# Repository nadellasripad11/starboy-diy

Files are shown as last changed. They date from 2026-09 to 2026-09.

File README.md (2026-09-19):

# starboy diy

a chrome star keychain with a little animated eye in the middle. shake it and the eye gets dizzy, take it somewhere cold and it starts shivering, yell near it and it gets nervous. leave it alone long enough and it falls asleep.

**see it live → [starboy-diy.nadellasripad11.workers.dev](https://starboy-diy.nadellasripad11.workers.dev/)** (the eyes on the site run the same code as the firmware)

it's my handbuilt take on the [creature starboy](https://lilguy.net). i wanted one, and more than that i wanted to know how one works inside, so i designed the shell from scratch in openscad, picked the smallest parts i could find that would fit, and wrote the eye animations myself.

<p align="center">
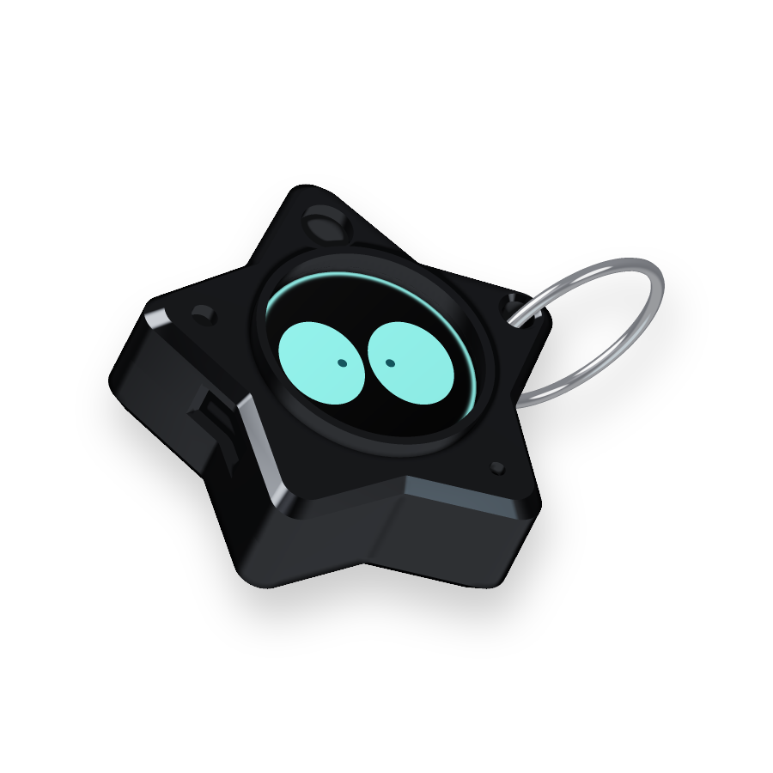
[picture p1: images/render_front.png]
front of the black chrome star shell with the round display and a keyring through its point
  
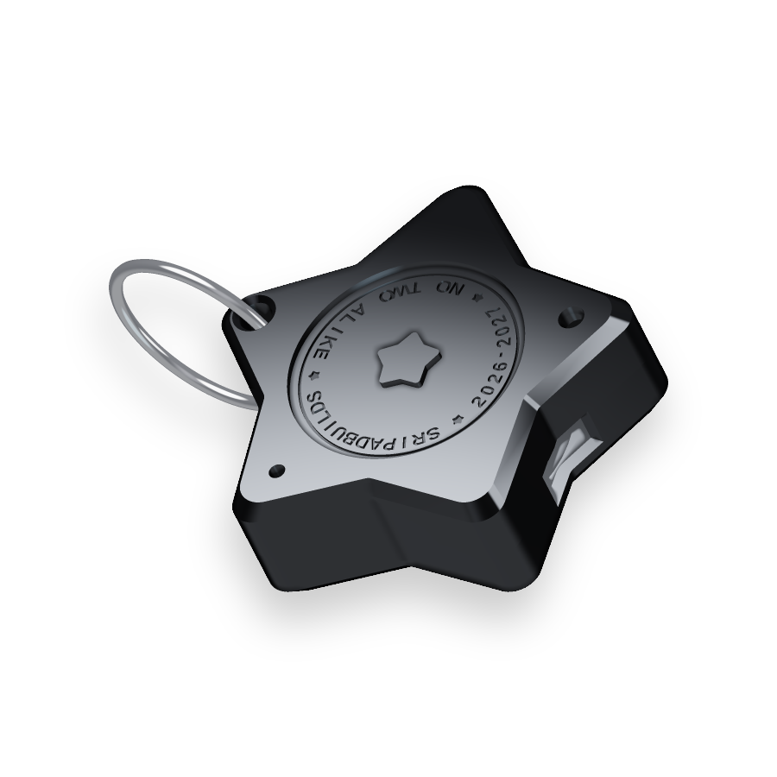
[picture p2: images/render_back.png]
back of the star shell with the engraved sripadbuilds medallion
  
</p>

---

## how it works

the brain is a seeed xiao esp32c3, a board about the size of a thumbnail with a battery charger built in. it drives a 1.28" round screen that acts as the eye, and it listens to three sensors:

- an **mpu6050** that feels shaking and tilting
- a **ds18b20** that pokes out of a tiny vent to read the air temperature
- a **max4466** mic that hears loud sounds

a small lipo sits at the back, and it charges through the xiao's usb-c port, which lines up with a cutout in the shell. the whole thing is 20.5mm thick and clips onto your pants.

---

## what the eye does

| if you... | the eye... |
|---|---|
| shake it hard for a second | gets dizzy, then angry, then calms down |
| take it below 10°c | gets chilly, shivers, then freezes with a blue tint |
| make a loud noise | jumps, then darts around nervously |
| tilt it | looks toward the ground |
| ignore it for 25s | starts dozing and the screen dims |
| ignore it for 75s | falls asleep and breathes slowly |
| shake it or make noise while it sleeps | wakes up |
| just let it sit | cycles through 50 little expressions |
| wait around | every so often plays one of 20 rare effects like rainbow eyes, hearts, glitches, matrix rain or a galaxy swirl |

the first time a star turns on, it rolls one of 100 colorways and one of 4 eye shapes (dot, circle, cat or acorn) and keeps them forever. some colorways are way rarer than others, so your eyes could be a 0.4% pull.

---

## what's in here

- [`cad/starboy_assembly.step`](CAD/starboy_assembly.step): the full 3d assembly (front, back and bezel)
- [`cad/starboy_star.scad`](CAD/starboy_star.scad): the parametric openscad file everything comes from
- [`stl/`](stl/): print-ready front, back and bezel
- [`firmware/`](firmware/starboy_firmware/): the arduino code, the screen config and the pin-by-pin wiring
- [`bom.csv`](BOM.csv): parts, prices and buy links
- [`bom.md`](BOM.md): the same list in plain words, plus how the parts work together
- [`build.md`](BUILD.md): printing, painting and putting it together

there's no custom pcb. everything is hand-wired to the xiao with thin 30awg wire, because that's the only way it all fits in the shell.

---

## what it costs

i'm building two stars, and everything for both comes to **$134.74**, filament included. it's all from amazon, so it shows up in a few days instead of a month. the full list is in [bom.csv](BOM.csv).

most parts come in multi-packs, so only the xiao and the battery get bought twice.

---

## wiring

wiring diagram

every module runs off the xiao's 3.3v pin. if you want every single connection spelled out, it's in [wiring.md](firmware/starboy_firmware/WIRING.md).

---

## printing and finishing

print the three files in [`stl/`](stl/) in white petg. everything gets chromed anyway, so one color is all you need. petg holds up way better than pla when it's hanging off a belt loop every day or sitting in a hot car. orientation and supports are in [build.md](BUILD.md).

for the chrome look, sand it smooth (400, then 800, then 1500), hit it with plastic primer, spray the chrome, and buff it lightly with 0000 steel wool once it's dry.

---

## flashing the firmware

open `firmware/starboy_firmware/starboy_firmware.ino` in the arduino ide, pick **xiao_esp32c3** as the board, and turn on **usb cdc on boot**.

install these from the library manager:

- tft_espi by bodmer
- adafruit mpu6050
- adafruit unified sensor
- dallastemperature
- onewire

one extra step for tft_espi: copy [`user_setup.h`](firmware/starboy_firmware/User_Setup.h) into its library folder so it knows about the round screen and which pins it's on.

before closing the shell, flash [`firmware/hardware_test`](firmware/hardware_test/hardware_test.ino) first. it checks the screen, backlight and all three sensors one by one and tells you which wire to fix. once the real firmware is on, open the serial monitor and type `help` for the tuning console.

both sketches compile clean for the xiao esp32c3 (esp32 core 3.3.11).

### checking everything at once

```
node tools/test_all.js --compile
```

runs the parity check, the mood tests, the seed tests and the demo tour check, then builds both sketches (point `ARDUINO_CLI` at arduino-cli if it isn't on your PATH). drop `--compile` for the 3-second version. the sections below explain each check.

### keeping the eyes in sync

the eye design lives in the firmware and in the website's copy of the renderer. after changing colorways, shapes or thresholds, run:

```
node tools/check_parity.js
```

it checks ~300 values across the firmware, the site, the preview page and the sensor sandbox (colorways, odds, pupil shapes, geometry, thresholds and mood timings), and fails with the exact file and value if anything drifted.

the mood logic has its own tests too, run with a fake clock so the slow paths (freezing, falling asleep) finish instantly:

```
node tools/test_mood.js
```

### choosing a star's eyes

the website rolls eyes with the exact same math as the firmware. tap any look on the [eye looks page](https://starboy-diy.nadellasripad11.workers.dev/eyes.html) and it gives you a command like `seed 1da79c35`. type that in the star's serial console and he gets those eyes for good. it also works backwards: paste the seed a star prints on boot to see which look he rolled.

```
node tools/test_seed.js
```

checks the port against a second reference implementation, confirms the odds over 400,000 rolls, and finds a working seed for all 400 looks.

---

## about the battery

the xiao doesn't have a battery plug, just two little pads on the bottom marked bat+ and bat−. so the plug gets cut off the battery and the wires get soldered straight onto those pads. check which wire is which with a multimeter before soldering, since cheap batteries don't always use red for positive.

a full charge lasts around 4 hours, and the screen dims itself whenever the eye gets sleepy to save power.

---

## credits & legal

this is an **unofficial fan build**. it's inspired by the starboy from [creature](https://lilguy.net), and it isn't affiliated with, endorsed by, or sold by them. "starboy" is their name. i'm not selling these, just building my own and sharing how.

- the shell cad, firmware, website and docs are my own work. **all rights reserved**, so please don't copy, reuse or redistribute any of it without asking first. see [LICENSE](LICENSE)
- the eye style and the 100 colorway colors and odds are based on creature's public eye gallery. the colorway names are my own
- libraries: [TFT_eSPI](https://github.com/Bodmer/TFT_eSPI) (FreeBSD), Adafruit MPU6050 + Unified Sensor (BSD), DallasTemperature + OneWire (LGPL / MIT-style). each keeps its own license
- site fonts are Figtree and Nunito from Google Fonts (SIL Open Font License)

made by [@nadellasripad11](https://github.com/nadellasripad11) · sripadbuilds

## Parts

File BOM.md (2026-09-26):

# bill of materials

everything i need to build **two** stars, bought from the cheapest reliable place for each part. prices checked 2026-09-25.

**total: $91.88** in parts, down from $134.74 when everything came from amazon → [BOM.csv](BOM.csv)

| part | qty | price | where | what it's for |
|---|-----|---|---|---|
| seeed studio xiao esp32c3 | 2 | $9.98 | [seeed studio](https://www.seeedstudio.com/Seeed-XIAO-ESP32C3-p-5431.html) | main board with a built-in lipo charger, one per star |
| gc9a01 1.28" round tft | 2 | $8.96 | [aliexpress](https://www.aliexpress.us/item/3256808098235758.html) | the eye |
| gy-521 mpu6050 | 2 | $3.76 | [aliexpress](https://www.aliexpress.us/item/3256808332288788.html) | shake + tilt |
| max4466 mic amp | 2 | $3.48 | [aliexpress](https://www.aliexpress.us/item/3256805885526362.html) | loud sound detection (pick the max4466 option) |
| ds18b20 to-92 (umw) | 2 | $1.15 | [lcsc C376006](https://www.lcsc.com/product-detail/C376006.html) | cold detection |
| 4.7kΩ resistors (100) | 1 | $0.62 | [lcsc C120071](https://lcsc.com/product-detail/Carbon-Film-Resistors_4-7KR-472-5_C120071.html) | ds18b20 pull-up |
| eemb 402535 3.7v 320mah lipo | 2 | $19.98 | [amazon](https://www.amazon.com/dp/B08215N9R8) | 25.5×36×4.3mm with a protection circuit, one per star |
| 30awg silicone wire, 5 colors | 1 | $6.96 | [aliexpress](https://www.aliexpress.us/item/3256808281675998.html) | wiring inside the shell (pick 30awg) |
| spring carabiner keyrings (10) | 1 | $2.96 | [aliexpress](https://www.aliexpress.us/item/3256807751442375.html) | pants and bag clip |
| stainless split rings 25mm (10) | 1 | $1.53 | [aliexpress](https://www.aliexpress.us/item/3256805611374476.html) | through the keyring hole |
| rust-oleum plastic primer 12oz | 1 | $6.97 | [amazon](https://www.amazon.com/dp/B003CT498U) | lets the chrome stick to the print |
| rust-oleum bright coat chrome 11oz | 1 | $6.47 | [amazon](https://www.amazon.com/dp/B000Z8DGXK) | chrome finish |
| creality petg 1.75mm 1kg | 1 | $14.81 | [aliexpress](https://www.aliexpress.us/item/3256812523172305.html) | star shells and bezel rings |
| prototype board 5×7cm, 1.2mm (10) | 1 | $4.25 | [aliexpress](https://www.aliexpress.us/item/3256807718543888.html) | the board everything solders onto, cut into a circle to sit behind the display |
| | | **$91.88** | | |

## what changed and why

- **aliexpress for the modules.** the display, mpu6050, mic amp, wire and keyrings cost a fraction of the amazon multi-packs. i went by listings with hundreds or thousands of sales and good ratings, not the cheapest one, and priced them at the normal price, not the one-time new-shopper deal.
- **seeed's own store for the xiao.** $4.99 instead of $9.90, and it's the genuine board. the cheap 3-packs on aliexpress don't say they're seeed, and this build depends on the xiao's battery charger.
- **lcsc for the temperature sensor and resistor.** lcsc sells real parts with datasheets. cheap ds18b20s on aliexpress are commonly clones.
- **a prototype board instead of loose wires.** the modules solder onto a small perfboard cut into a circle to sit behind the display (round blank ones aren't sold, so cutting one from a rectangle is the normal way), so everything is mounted instead of hanging on wires. i went with 1.2mm boards, the thinnest common size, because the shell is tight on depth.
- **the battery stays the eemb.** decent aliexpress cells were only about $1 cheaper, with no certification. it's a lithium cell worn on a belt loop, so it's not worth saving $2 on.
- **paint stays on amazon.** spray cans can't be shipped by air from china.

## shipping and fees

the total above is parts only. what gets added at checkout:

- **aliexpress:** shipping and any us import charges are shown in the cart. several of these listings advertise free shipping, and grouping them in one order helps
- **seeed studio:** shipping is shown at checkout
- **lcsc:** shipping plus us tariffs, shown in the cart. it's only two cheap parts, so if lcsc's shipping ends up more than they're worth, an aliexpress ds18b20 pack with good reviews is the fallback
- **amazon:** free shipping on the battery and paint with prime or over $35

## how the parts work together

- everything runs on the xiao's 3.3v rail, and the display, mpu6050, max4466 and ds18b20 are all rated for 3.3v
- the xiao charges the lipo over usb-c, so there's no separate charger board
- the battery's protection circuit handles over-charge, over-discharge and shorts
- the ds18b20 needs one 4.7kΩ pull-up on its data line, soldered on the prototype board
- the prototype board adds 1.2mm to the stack inside the shell, so the shell has to leave room for it
- the to-92 ds18b20 is small enough to sit in the 4mm temperature vent
- 30awg silicone wire folds into the shell without stressing the solder joints

tools not listed (already have them): soldering iron, solder, flush cutters, multimeter, usb-c cable, 3d printer.

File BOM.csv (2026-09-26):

Item Name | Quantity | Unit Price (USD) | Total Price (USD) | Supplier | Link | Notes
Seeed Studio XIAO ESP32C3 | 2 | 4.99 | 9.98 | Seeed Studio | https://www.seeedstudio.com/Seeed-XIAO-ESP32C3-p-5431.html | Genuine board with the built-in LiPo charger; one per star (was $9.90 each on Amazon)
GC9A01 1.28in Round TFT 240x240 SPI | 2 | 4.48 | 8.96 | AliExpress | https://www.aliexpress.us/item/3256808098235758.html | The eye; 4.6 stars and 1000+ sold; one per star
GY-521 MPU6050 Accelerometer/Gyro | 2 | 1.88 | 3.76 | AliExpress | https://www.aliexpress.us/item/3256808332288788.html | Shake and tilt over I2C; 4.7 stars and 500+ sold
MAX4466 Electret Mic Amplifier | 2 | 1.74 | 3.48 | AliExpress | https://www.aliexpress.us/item/3256805885526362.html | Loud sound detection; pick the MAX4466 option (the listing also sells MAX9814); 4.8 stars
DS18B20 TO-92 Temperature Sensor (UMW) | 2 | 0.5751 | 1.15 | LCSC | https://www.lcsc.com/product-detail/C376006.html | LCSC C376006; a real compatible part (cheap AliExpress DS18B20s are often clones)
4.7k Ohm 1/4W Through-Hole Resistor (100 pcs) | 1 | 0.62 | 0.62 | LCSC | https://lcsc.com/product-detail/Carbon-Film-Resistors_4-7KR-472-5_C120071.html | LCSC C120071; DS18B20 pull-up; 100 is LCSC's minimum at $0.0062 each
EEMB 402535 3.7V 320mAh LiPo Battery | 2 | 9.99 | 19.98 | Amazon | https://www.amazon.com/dp/B08215N9R8 | Kept on purpose: UL certified with a protection circuit; AliExpress cells saved about $1 each and are uncertified
30AWG Silicone Wire (5 colors) | 1 | 6.96 | 6.96 | AliExpress | https://www.aliexpress.us/item/3256808281675998.html | Pick the 30AWG option; 4.8 stars and 5000+ sold
Round Spring Carabiner Keyrings (10 pcs) | 1 | 2.96 | 2.96 | AliExpress | https://www.aliexpress.us/item/3256807751442375.html | Pants and bag clip; 4.9 stars and 1000+ sold
Stainless Steel Split Key Rings 25mm (10 pcs) | 1 | 1.53 | 1.53 | AliExpress | https://www.aliexpress.us/item/3256805611374476.html | Goes through the keyring hole in the star's point; 4.8 stars
Rust-Oleum 249323 Automotive Plastic Primer 12oz | 1 | 6.97 | 6.97 | Amazon | https://www.amazon.com/dp/B003CT498U | Aerosol: can't ship from AliExpress or LCSC
Rust-Oleum Bright Coat Metallic Chrome Spray 11oz | 1 | 6.47 | 6.47 | Amazon | https://www.amazon.com/dp/B000Z8DGXK | Aerosol: can't ship from AliExpress or LCSC
Creality PETG Filament 1.75mm 1kg | 1 | 14.81 | 14.81 | AliExpress | https://www.aliexpress.us/item/3256812523172305.html | Official Creality store; shells and bezels for both stars
Prototype Board 5x7cm 1.2mm Single-Sided (10 pcs) | 1 | 4.25 | 4.25 | AliExpress | https://www.aliexpress.us/item/3256807718543888.html | The modules solder onto this instead of hanging on loose wires; cut into a circle about the size of the display (round blank boards aren't sold); 1.2mm is the thinnest common size; 4.9 stars and 10000+ sold
TOTAL (parts only) |  |  | 91.88 |  |  | Before shipping and import fees (see BOM.md); the old all-Amazon list was $134.74

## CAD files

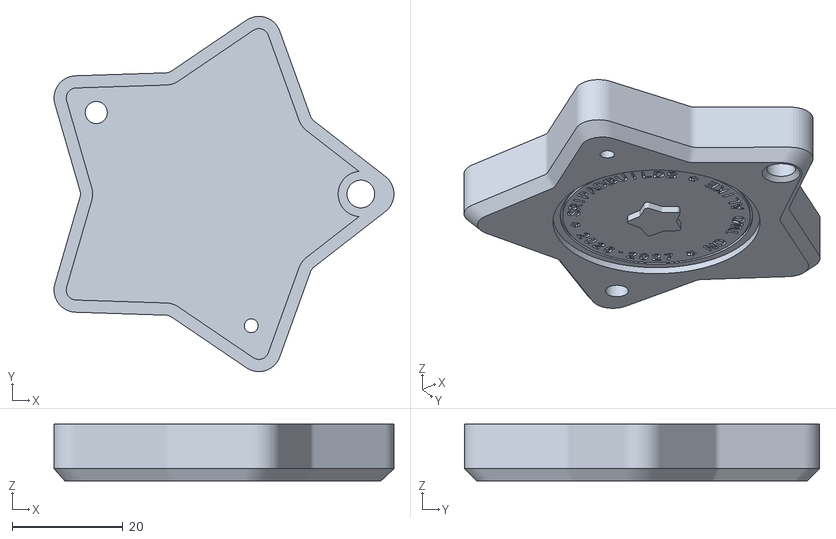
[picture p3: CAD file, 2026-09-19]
stl/starboy_back.stl
61.3 x 64.1 x 10.2

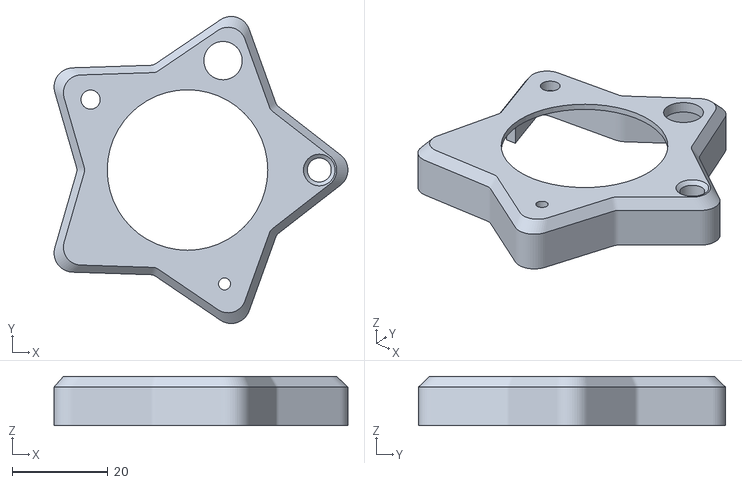
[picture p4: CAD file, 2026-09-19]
stl/starboy_front.stl
61.3 x 64.1 x 10.2

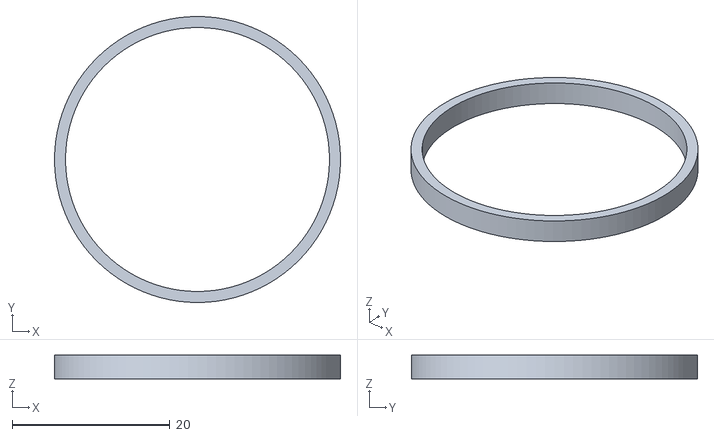
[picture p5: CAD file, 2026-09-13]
stl/starboy_bezel.stl
36.3 x 36.3 x 3.00

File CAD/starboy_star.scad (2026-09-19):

// ============================================================
// STARBOY-STYLE STAR SHELL  (metallic keychain replica, DIY)
// ============================================================
// Free software: OpenSCAD (openscad.org). Open this file, tweak
// the variables below (live preview updates instantly), then set
// `part` (below) to the piece you want and export STL:
//   "front"  -> the front shell half (has the screen pocket)
//   "back"   -> the back shell half (has the engraved medallion)
//   "bezel"  -> just the printable chrome bezel ring around the screen
//   "ring"   -> a printable open jump-ring (or just buy metal ones, see notes)
//   "clip"   -> the pants/pocket clip
//   "preview"-> everything assembled together, for looking at only
//
// PRINT NOTES
// - Print "front" and "back" separately, sand smooth, chrome-spray
//   the OUTSIDE only (mask the inside faces / mating lip if you can).
// - The back medallion is engraved right in the print (text +
//   sunburst + little star badge). You can paint it as-is for a
//   "brushed" look, OR glue a bought engraved steel tag over it if
//   you want real metal there instead — the recess is sized for that.
// - The clip is a plastic spring clip like a pocket-knife clip. PETG
//   flexes better than PLA and is less likely to snap — print the
//   clip in PETG if you have it. Test-fit on your actual pants
//   waistband/pocket edge before gluing it on for good.
// - The "ring" part is a printable open jump ring. Printed rings this
//   small are genuinely more fragile than a $3 bag of metal jump
//   rings — it's included because you asked for it in the file, but
//   for something you'll actually clip to your pants every day, a
//   real metal jump ring/carabiner clip is the safer call.
//
// ============================================================
// COMPONENT FIT — measured, and what drives the dimensions
// ============================================================
// Every number below was used to size the shell. If you swap a part
// for a different one, re-check this table before printing.
//
//   PART                          L x W x H (mm)      WHERE IT GOES
//   GC9A01 1.28" round display    37.5 dia x 5.4      front pocket, centred
//     ^ the PCB. The 32.4 quoted everywhere is the GLASS - sizing to that
//       number is exactly why the pocket had to be re-cut as a step.
//   Seeed XIAO ESP32C3            21.0 x 17.8 x 4.5   behind display, USB-C
//                                                     flush to the 180deg wall
//     ^ has the LiPo charger built in (the SuperMini does NOT). 4.5 is the
//       height over the USB-C socket; the PCB itself is 1.2.
//   MPU6050 GY-521 (no headers)   21 x 16 x ~3.0      stacked behind the XIAO
//     ^ ~3.0 is an estimate (1.6 PCB + chips); not published anywhere.
//   LiPo 402530 (300mAh)          30.0 x 25.0 x 4.0   stacked at the back
//   DS18B20 (TO-92)                4.3 dia x 5.2      at the temp vent, 144deg arm
//   MAX4466 mic board (Adafruit #1063)       x 7.8   at the mic port, 288deg arm
//     ^ 7.8 is Adafruit's figure with the mic fitted. Depth there is ~15 so it
//       fits; footprint wasn't published, so dry-fit it against the arm.
//   OV2640 camera (optional)       8.0 dia lens       camera pocket, 72deg arm
//
// DEPTH BUDGET (the tight axis):
//   body 20.5 - display pocket 5.5 - back wall 3.0      = 12.0 available
//   XIAO 4.5 + GY-521 3.0 + battery 4.0                 = 11.5 used
//   -> 0.5mm slack. Do not reduce body_thickness below 20.5.
//
//   The back wall is 3.0 rather than 2.2 because the medallion dish and
//   its engraving are cut into it. At 2.2 the engraved text punched
//   straight through into the cavity. There is an assert() guarding this.
//
// WIDTH CHECK (the centre region, bounded by the valleys):
//   usable central circle = 2 x (inner_radius - wall) = 41.6 dia
//   battery diagonal sqrt(30^2+25^2) = 39.1  -> fits
//
// The XIAO sits off-centre toward the 180deg valley so its USB-C is flush
// with the inside of the wall; the charge cutout is sized for a cable's
// plastic overmold so the plug fully seats.
// ============================================================

/* [Overall size] */
// Proportions taken off the reference photos: a BIG central mass with
// SHORT, crisp points (the medallion reads ~55% of total width), not
// long thin spikes. The fat centre is also what makes the hardware fit —
// the 32.4mm display needs a ~40mm flat central region to sit in.
star_points      = 5;      // number of lobes
outer_radius     = 36;     // mm, tip-to-centre of each point
inner_radius     = 23;     // mm, valley radius. ~0.64 x outer = reference proportion.
                            // Do NOT drop this: the display's PCB ledge is 19.3mm in
                            // radius and the cavity wall has to clear it. Guarded by
                            // an assert below.
body_thickness   = 20.5;   // mm, total thickness. Sized directly from the measured
                            // component stack — see COMPONENT FIT below. Leaves
                            // 12.0mm behind the display for an 11.5mm stack.
edge_round       = 3.5;    // mm, unused by current geometry, kept for reference
tip_round        = 1.8;    // mm, how rounded each outer tip is in the flat 2D outline
valley_round     = 4;      // mm, how rounded each inner valley is in the flat 2D outline
wall             = 2.2;    // mm, side + front shell wall thickness
back_wall        = 3.0;    // mm, BACK wall is thicker on purpose: the medallion
                            // dish (1.2) plus its engraving (0.5) eat into it, and
                            // at 2.2 the engraved text cut straight through into
                            // the electronics cavity. Leaves a 1.8mm solid floor.

/* [Chamfer] */
// The body is a flat-faced slab (screen/medallion sit flush in true
// flat planes) with a tapered bevel near the top/bottom edges — this
// is what gives the faceted, jewel-cut look in the reference photos,
// instead of an organic rounded blob.
bevel_edge  = 2.2;    // mm, how much of the thickness is tapered at each face
bevel_scale = 0.93;   // profile shrink factor at the very edge of the bevel.
                       // Keep this HIGH (>=0.90). scale() shrinks toward the
                       // origin, so an aggressive value pulls the front face in
                       // past the display pocket edge in the valley directions
                       // and the screen ends up overhanging empty space.

/* [Eye / screen] */
// GC9A01 1.28" round module (Waveshare spec): the 32.4mm figure quoted
// everywhere is the DISPLAY GLASS, not the board — the PCB is Φ37.5mm.
// Sizing a 33.5mm pocket to "32.4mm module" does not fit. So the pocket
// is stepped: a 33.5mm opening at the face that the glass shows through,
// over a wider 38.6mm ledge that actually holds the PCB.
screen_offset_x     = 0;    // centred — margin to the valley edge is tight,
screen_offset_y     = 0;    // don't offset without re-running the asserts
screen_diameter     = 33.5; // mm, the visible opening (glass is 32.4)
screen_pcb_dia      = 38.6; // mm, Φ37.5 PCB + 1.1 clearance
screen_lip_depth    = 1.2;  // mm, depth of the narrow opening = retaining lip
screen_pocket_depth = 5.5;  // mm total; module is ~5.4mm thick
bezel_wall          = 1.4;  // mm, thickness of the printable chrome bezel ring — kept
                              // slim so the display doesn't dominate the face
bezel_height        = 3;    // mm
// The round module is Φ37.5 with a small tab sticking out to 40.4 overall
// that carries the 8-pin header. The notch has to clear that tab: it is
// SHALLOW radially and WIDE tangentially (these two were swapped before,
// which would have fouled the tab).
ribbon_slot_radial = 5;     // mm, how far the notch reaches outward
ribbon_slot_wide   = 14;    // mm, tangential width — tab is ~12mm

/* [Camera — optional] */
// Physical mounting space for a small camera module (e.g. OV2640),
// styled like the lens turret in the reference photos. Not required
// for the shake/cold/sound reactions — only matters if you later add
// face or gesture detection (needs an ESP32-S3 + real image processing,
// well beyond the C3). Cheap to include the hole now either way.
// Sits on the 72-degree arm at r=24: the arm is ~13.2mm wide there, so an
// 8mm lens leaves ~2.6mm of wall each side, and its inner edge clears the
// display bezel (r=18.15) by 1.85mm.
camera_dia          = 8;    // mm, lens opening
camera_bezel_wall   = 1.4;  // mm, raised ring around the lens
camera_pocket_depth = 2.6;  // mm
camera_r            = 24;   // mm from centre, along its arm
camera_ang          = 72;   // degrees
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

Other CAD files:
CAD/starboy_assembly.step

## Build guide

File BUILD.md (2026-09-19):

# STARBOY DIY — Build Guide

Shell: **body ~64 × 61mm, 20.5mm thick**, with the keyring hole through the right-hand point.
Print `stl/starboy_front.stl`, `stl/starboy_back.stl`, and `stl/starboy_bezel.stl`.

Parts, prices and links: **[BOM.csv](BOM.csv)** · **[BOM.md](BOM.md)**

---

## ⚠️ Things that will bite you

**0. The display's "32.4mm" is the GLASS, not the board.** The PCB is
**Φ37.5mm**. Every listing quotes the glass size. The pocket is stepped to
hold the real board — but it also means **Adafruit #6178 will not fit**
(it's a 42.4 × 36.2mm rectangle). Buy a round-PCB module.

**1. The display's pin header.** GC9A01 modules ship with an 8-pin header
soldered to the back. That header sticks ~8mm into the cavity — straight
into the space the XIAO needs. **Desolder it and solder wires flat to the
pads instead.**

**2. The GY-521's headers.** With headers soldered it's ~11mm tall. The
depth budget assumes the board without them (~3.0mm). Leave them off.

**3. Battery thickness is a hard ceiling.** The depth budget is 12.0mm. The
EEMB 402535 in the BOM is 4.3mm thick, which brings the stack to 11.8mm and
leaves just 0.2mm of slack (the CAD was first sized for a 4.0mm cell). Its
36 × 25.5mm footprint fits the cavity rotated 90°. Measure the battery and
the GY-521 before closing up; if they're thicker than listed, the shell's
depth will need adjusting.

**4. Battery wiring.** The XIAO has BAT+ / BAT− **solder pads** on its
underside, not a plug. Cut the battery's JST plug off and solder the wires.
**Check polarity with a multimeter** — cheap leads don't follow one colour
standard, and reversing it can destroy the board.

**5. Charge rate.** The XIAO fast-charges at 380mA — about 1.2× the 320mAh
battery's capacity, above the usual 1C limit. Charge it where you can see
it and unplug it if it gets warm.

---

## Verified fit

Depth is the tight axis. These numbers are asserted at build time in the
SCAD file, so they cannot silently drift:

```
body 20.5  −  display pocket 5.5  −  back wall 3.0    =  12.0mm available
XIAO 4.5   +  GY-521 ~3.0  +  battery 4.0             =  11.5mm used
                                                         0.5mm slack
```

The XIAO's 4.5mm is its height over the USB-C socket. The GY-521's ~3.0mm is
an estimate — nobody publishes it. **Measure both before the final print.**

Width, at the centre (bounded by the valleys):

```
usable central circle          = 41.6mm
battery diagonal (30×25)       = 39.1mm   fits
display PCB                    = 37.5mm   fits (38.6mm ledge)
```

**0.5mm of slack is not much. Dry-fit everything before gluing.**

---

## Feature placement

Front facing you, keyring to the right (0°):

| Angle | Feature | Size |
|---|---|---|
| 0° | Keyring hole, 27.5mm out along the point, sleeved through the hollow | 5mm, through, chamfered |
| 72° | Camera pocket (optional) | 8mm |
| 144° | DS18B20 vent | 4mm, through |
| 180° valley | USB-C charging cutout | 12.5 × 7.0mm |
| 288° | Mic sound port | 2.5mm, through |

The charging cutout is sized for a cable's **plastic grip**, not just the
metal plug — with a tight hole, the grip hits the wall before the plug seats.

The temp vent and mic port are **through-holes on purpose**. The DS18B20
must see outside air — sealed inside it just reads the board's own waste
heat and the cold/shiver behaviour never fires. Seat the sensor body in
the hole; that plugs it.

---

## Printing

- **Front half:** outer face **down** on the bed. No supports: the keyring
  hole is a plain vertical hole with a chamfer at the face.
- **Back half:** flat mating side **down**, engraving facing up. Supports
  (build plate only; tree supports come out easiest) inside the hollow —
  its roof is an unsupported span. Don't print it face-down: the 36mm
  medallion dish would print as a sagging bridge and wreck the text.
- **Bezel ring:** flat, no supports. It glues **on top of** the front face
  around the opening.
- **Layer height:** 0.16mm or finer — the back engraving is only 0.5mm deep.
- **Walls:** 3+ perimeters. The shell is load-bearing round the keyring hole.
- **Material:** PETG. The keyring hole takes the load every day, and PETG
  handles that (and a hot car) far better than PLA. White for everything,
  since it all gets chromed.
- **Do not scale.** Every clearance here is absolute.

### Finishing
Sand 400 → 800 → 1500, Rust-Oleum plastic primer, then Rust-Oleum Bright
Coat chrome on the **outside only**. Keep paint off the flat faces where the two halves meet —
paint thickness there will stop them seating. Polish with 0000 steel wool.

---

## Assembly order

1. Dry-fit the whole stack first. Confirm the halves close before any glue.
2. Leave the headers off the display and GY-521; wire them flat.
3. Drop the display into the front half **from the inside** — the board
   (Φ37.5mm) is wider than the 33.5mm face opening, so it seats against the
   lip from behind. Then glue the bezel ring onto the outside of the face.
4. XIAO behind the display, pushed toward the 180° valley so its USB-C sits
   **flush against the inside of the wall**. Plug a cable in and make sure it
   seats fully before gluing.
5. GY-521 flat behind the XIAO — keep it parallel to the star's face, since
   shake and tilt depend on its orientation.
6. DS18B20 into the 144° vent, mic into the 288° port.
7. Battery last, at the back: solder to the XIAO's BAT+ / BAT− pads,
   polarity checked.
8. Flash and test **before** closing the shell.

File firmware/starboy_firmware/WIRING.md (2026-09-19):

# STARBOY DIY — Wiring, Libraries & Physical Build

## Shell dimensions (final, print-ready)

| | |
|---|---|
| Body | ~64 × 61 mm, keyring hole through the right-hand point |
| Thickness | 20.5 mm |
| Board | Seeed XIAO ESP32C3 (built-in LiPo charger) |
| Display | GC9A01 1.28" round, centred in the front face |
| Charging | XIAO's USB-C, through a cutout in the valley opposite the keyring |

The 20.5mm thickness is not arbitrary — it's driven by the component stack.
See the COMPONENT FIT table at the top of `CAD/starboy_star.scad`.

## Component placement

Looking at the **front** (display facing you), with the keyring at the right
(0°), features sit on the arms at these angles:

| Angle | Feature |
|---|---|
| 0° | Keyring hole (5mm, through) |
| 72° | Camera lens pocket (8mm) — optional |
| 144° | DS18B20 temperature vent (4mm, through-hole) |
| 180° (valley) | USB-C charging cutout (12.5 × 7.0mm) |
| 288° | MAX4466 mic sound port (2.5mm, through-hole) |

**The temperature vent is a through-hole on purpose.** If you seal the
DS18B20 inside, it reads the board's own waste heat and the cold/shiver
behaviour never triggers. It has to see outside air.

## Internal stack (front to back)

```
front face
  ├─ GC9A01 display        5.4mm   (inserted from inside, against the lip)
  ├─ XIAO ESP32C3          4.5mm   (USB-C flush against the 180° wall)
  ├─ GY-521 (no headers)  ~3.0mm
  └─ EEMB 402535 320mAh    4.3mm   (36 × 25.5mm, lies rotated 90° in the cavity)
back face
```
Total 11.8mm into 12.0mm available — only 0.2mm slack. The CAD was first
sized for a 4.0mm 402530 cell; the 402535 in the BOM is 0.3mm thicker. Its
footprint was checked against the real star outline (1.0mm to spare), but
the depth is now very tight and the GY-521's ~3.0mm is an estimate. Measure
the battery and the GY-521 when they arrive and dry-fit before gluing.

## Charging

The XIAO ESP32C3 has a LiPo charger built in (380mA fast / 40mA trickle).
Plug USB-C into the cutout and it charges the battery on its BAT pads. No
extra charger module is needed.

---

# Wiring & Libraries (v2.0 firmware)

## 1. Install TFT_eSPI (requires one-time config)

1. Arduino IDE → Library Manager → search **TFT_eSPI** by **Bodmer** → Install
2. Find your Arduino libraries folder (usually `Documents/Arduino/libraries/TFT_eSPI`)
3. Copy [`User_Setup.h`](User_Setup.h) from this folder into that library folder,
   **replacing** the existing `User_Setup.h`
4. This tells TFT_eSPI: GC9A01 driver, 240×240, and your exact SPI pins

## 2. Install the rest (Library Manager)

| Library | Author |
|---|---|
| Adafruit MPU6050 | Adafruit |
| Adafruit Unified Sensor | Adafruit |
| DallasTemperature | Miles Burton |
| OneWire | Jim Studt |

Board: **ESP32 (by Espressif)** → pick **XIAO_ESP32C3**
Also set: **USB CDC On Boot → Enabled** (so Serial.print debug works)

---

## Wiring

Pins are written as the XIAO's silkscreen label, with the GPIO number the
firmware uses in brackets. D0 (GPIO2) and D9 (GPIO9) are left free on
purpose — they're boot-mode strapping pins.

### GC9A01 1.28" Round TFT (SPI)
| TFT Pin | XIAO ESP32C3 |
|---|---|
| VCC | 3V3 |
| GND | GND |
| SCL/SCK | D8 (GPIO8) |
| SDA/MOSI| D10 (GPIO10) |
| DC | D6 (GPIO21)  |
| CS | D3 (GPIO5) |
| RST | 3V3 (tied high) |
| BL | D2 (GPIO4) — PWM, firmware dims it when asleep; do NOT tie to 3.3V |

### MPU6050 / GY-521 (I2C)
| GY-521  | XIAO ESP32C3 |
|---|---|
| VCC | 3V3 |
| GND | GND |
| SDA | D4 (GPIO6) |
| SCL | D5 (GPIO7) |
| AD0 | GND (address 0x68) |

### DS18B20 (OneWire)
| DS18B20 | XIAO ESP32C3 |
|---|---|
| VDD | 3V3 |
| GND | GND |
| DATA | D7 (GPIO20)  |
| (4.7kΩ resistor between DATA and VDD — comes in the DS18B20 pack) |

### MAX4466 Mic (analog)
| MAX4466 | XIAO ESP32C3 |
|---|---|
| VCC | 3V3 |
| GND | GND |
| OUT | D1 (GPIO3) |

### LiPo battery
| Battery | XIAO ESP32C3 |
|---|---|
| + | BAT+ pad (underside) |
| − | BAT− pad (underside) |

Cut the JST plug off and solder. **Check polarity with a multimeter first.**

---

## What it does — full behavior list

**Sensor-driven states:**

| Trigger | Behavior |
|---|---|
| Shake 1s+ | Dizzy spinning eyes → severe dizzy → recovering → angry |
| Keep shaking hard | Full rage state (deep red squint + heavy furrow) |
| Temp < 10°C | Chill → shiver → freeze (progressively icier, blue tint, crystalline overlay) |
| Loud sound | Startled → anxious darting eyes → overwhelmed |
| Tip it more than 25° from how it's been resting | Eyes look downhill, then settle within a few seconds as he gets used to the new angle (so hanging on a belt loop doesn't keep him tilted or awake) |
| 25s no interaction | Doze — eyes half close, brows droop, backlight dims |
| 75s no interaction | Full sleep — slow breathing blink, occasional dream state, backlight nearly off |
| Shake or sound during sleep | Wakes up ("just woke" expression) |

**Idle personality (cycles automatically, ~2.5-7s):**
neutral · content · happy · curious · bored · wondering · playful · glancing ·
cheerful · relaxed · shifty · noticing-something — 50 base expressions, each
blended smoothly into the next.

**Rare special animations** (checked every ~90s, 40% chance):
rainbow eyes · heart pupils · star pupils · glitch · matrix rain · hypnotic
spiral · loading spinner · error/X eyes · derp/cross-eyed · smug · crying ·
laughing · shocked · "dead" eyes · galaxy swirl · heartbeat pulse · fire
pupils · starfield dream · scanline glitch — 20 total, ~5 seconds each.

**Eye design:** each unit rolls its eyes on first boot (seed stored in
flash): one of 100 colorways and one of 4 shapes (dot 10%, circle 40%,
cat 30%, acorn 20%). Colorways are weighted, so the rarest ones come up
about 0.4% of the time.

---

## Test the parts first

Before soldering everything into the shell, flash
[`firmware/hardware_test/hardware_test.ino`](../hardware_test/hardware_test.ino).
It flashes the screen red/green/blue/white, fades the backlight, then checks
the MPU6050, DS18B20 and mic one by one and prints PASS/FAIL on the screen
and over Serial (115200). After that it goes live: shake it and the SHAKE bar
moves, clap and the SOUND bar moves. Every FAIL line says which wire to check.

## Upload Settings (Arduino IDE)

- Board: XIAO_ESP32C3
- USB CDC On Boot: Enabled
- If an upload won't start: hold the **BOOT** button, tap **RESET**, release BOOT, then upload.

## Tuning

No reflashing needed. Open the Serial Monitor at 115200 with newline line
endings and type commands:

```
status                 sensors, current mood, eyes and every threshold
hw                     which parts are detected, with the wire to check for anything missing
demo                   a ~77s tour for filming: loud room, cold, shaken, four rare effects,
                       falling asleep and waking up. `demo stop` ends it early
debug on               print shake / temp / sound once a second
set shake 12           shake needed to get dizzy (m/s² above gravity, default 16)
set cold 8             °C that starts the shiver (default 10)
set loud 900           mic swing that makes him anxious (default 600, depends on the gain trimmer)
set doze 25            seconds alone before dozing (default 25)
set sleep 75           seconds alone before full sleep (default 75)
set rare 90            seconds between rare effect chances (default 90)
set tempoffset -3      correct the temperature reading (default 0). the sensor sits next to
                       the board and battery, so compare `status` with a real thermometer once
save                   keep the values after a restart
defaults               back to factory values

mood shiver            jump to any mood (help lists them all)
fx fire                play any rare effect
fake temp 2            pretend it's cold, fake sound 2000 pretends it's loud, fake off
reroll                 roll new eyes, seed 1a2b3c4d sets exact ones
```

A good tuning loop: `debug on`, leave the star still for a minute to see
the quiet mic level, then set `loud` a few hundred above it.

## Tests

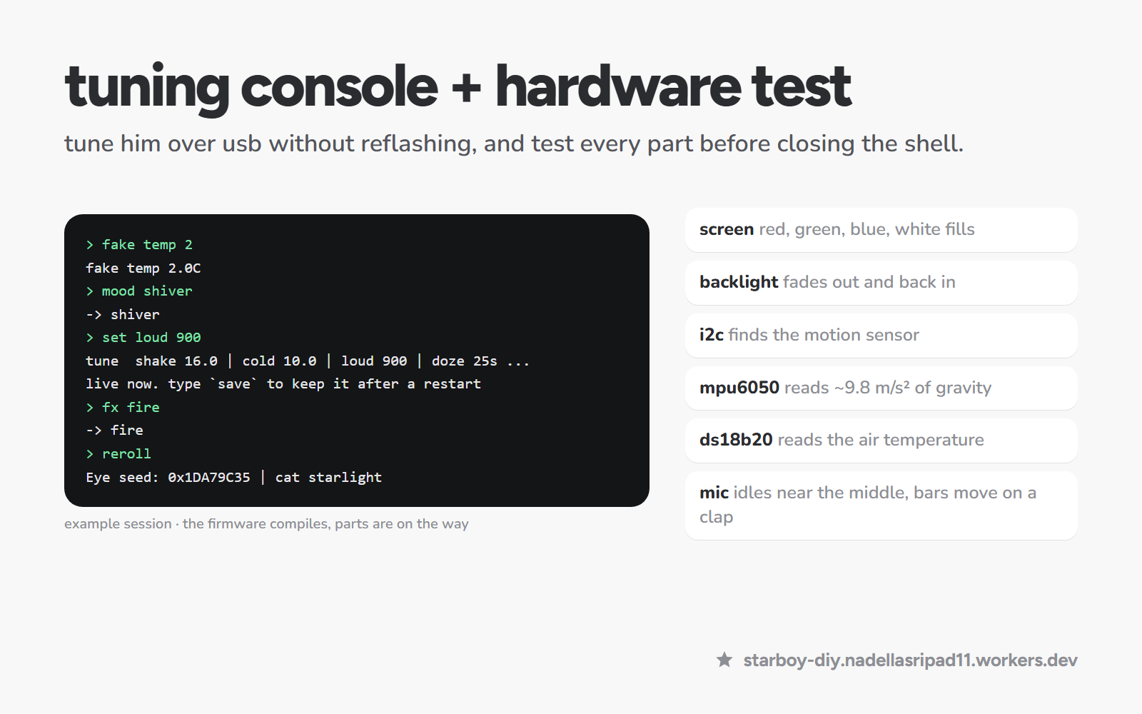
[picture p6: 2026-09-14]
devlog/photos/devlog3/4-console-and-hardware-test.png

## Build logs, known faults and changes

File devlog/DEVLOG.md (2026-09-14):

# devlog #2 · starboy diy

**tl;dr** i'm building a tiny wearable pet from scratch. he clips onto your belt loop, has a round screen for a face, and reacts to shaking, cold and loud noises. the shell, eyes and firmware are done, parts are next.

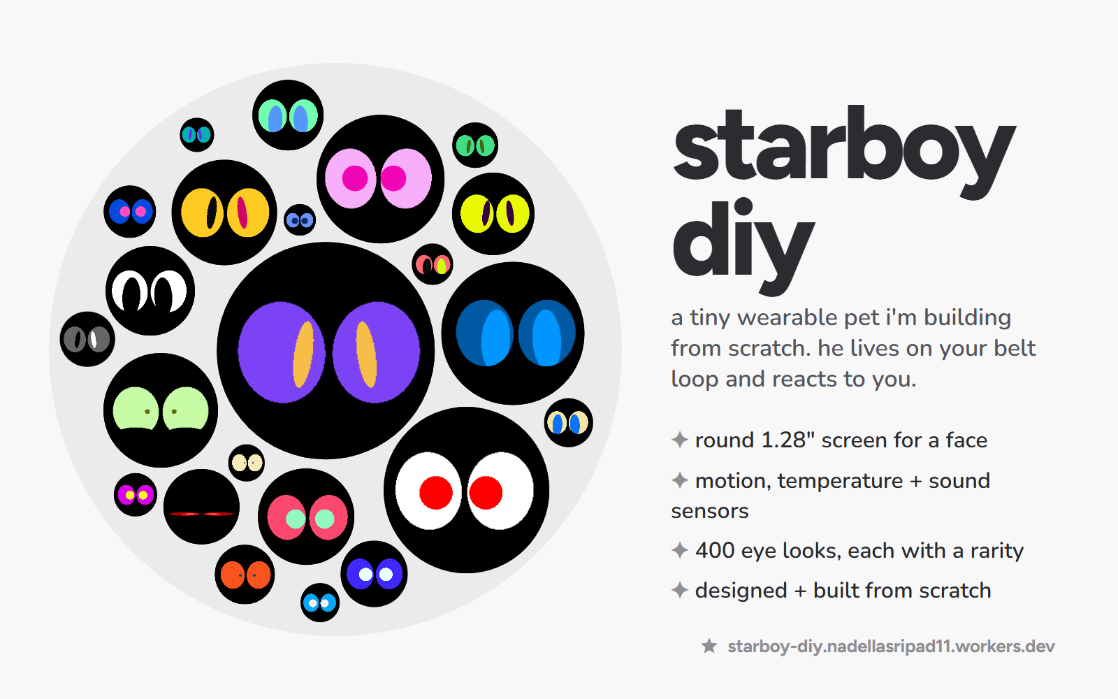
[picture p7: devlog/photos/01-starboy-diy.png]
starboy diy


---

## what i'm making

a chrome star about the size of a keychain, with a 1.28" round screen in the middle that acts as his eye. inside is a thumb-sized esp32 board and three sensors: an accelerometer, a temperature sensor and a microphone. shake him and he gets dizzy then mad. take him somewhere cold and he shivers. yell near him and he gets nervous. ignore him and he falls asleep.

## designing the shell

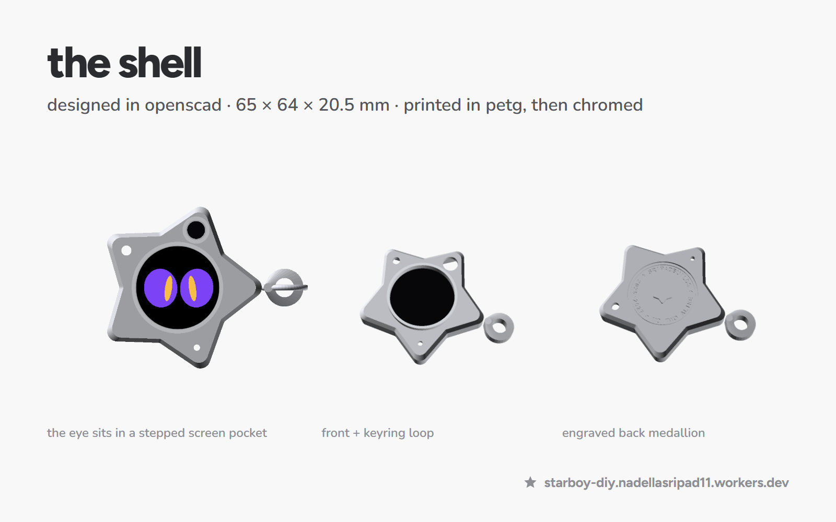
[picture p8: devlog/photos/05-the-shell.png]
the shell


i designed the whole shell in openscad. the hardest part was depth. the screen, board, motion sensor and battery all stack inside a body that's only **20.5mm** thick, which leaves **0.5mm** of slack. i put asserts in the cad file so if a dimension ever changes and something stops fitting, it refuses to build instead of letting me print a broken shell.

one thing that bit me: every listing says the round screen is 32.4mm, but that's just the glass. the actual circuit board is **37.5mm**. so the screen pocket is stepped: a narrow opening you see through, with a wider ledge behind it that holds the board.

the back has an engraved medallion, and there are through-holes for the temperature sensor and mic so they read the outside air instead of the heat from the board.

## the eyes

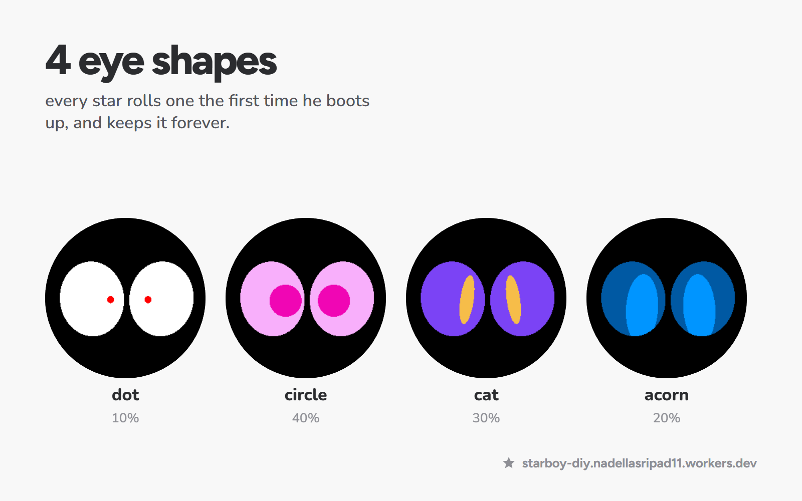
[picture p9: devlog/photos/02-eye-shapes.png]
4 eye shapes


this is the part i'm proudest of. every star rolls his own eyes the first time he turns on and keeps them forever. there are **4 shapes** (dot, circle, cat and acorn) and **100 colorways**, so **400 looks**, each with its own rarity. the rarest ones only come up 0.04% of the time.

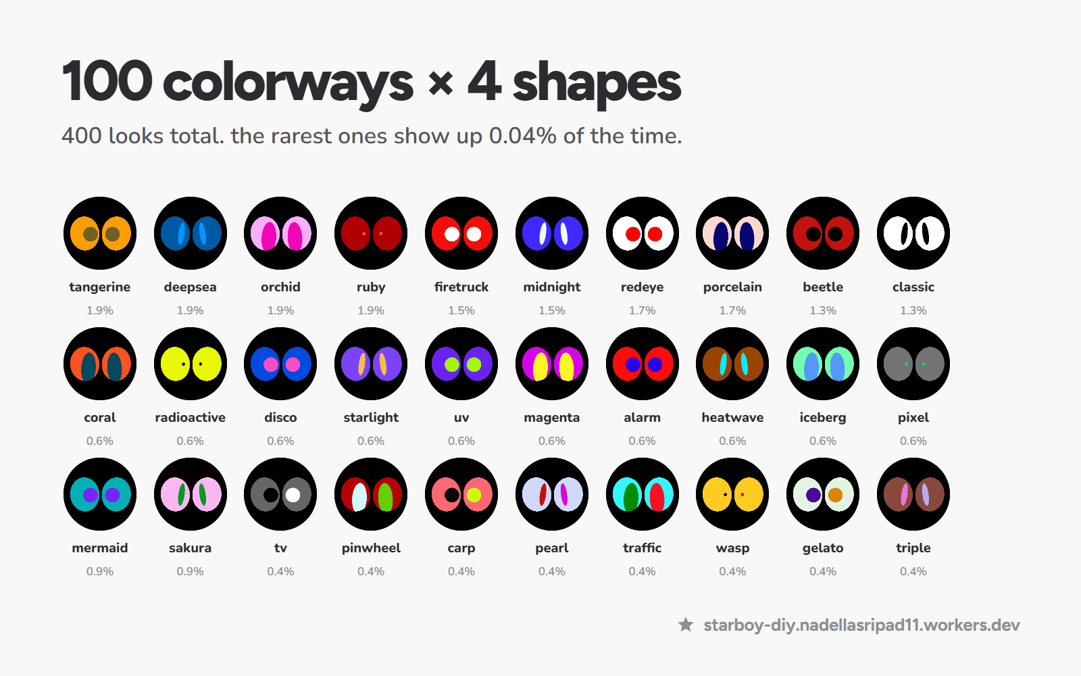
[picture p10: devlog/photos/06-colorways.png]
100 colorways


each eye is drawn row by row on a 240×240 screen: a tilted oval with a pupil clipped to its edge. blinks squash the eye instead of just covering it, and happy moods push the bottom lid up into a little arch.

## making him react

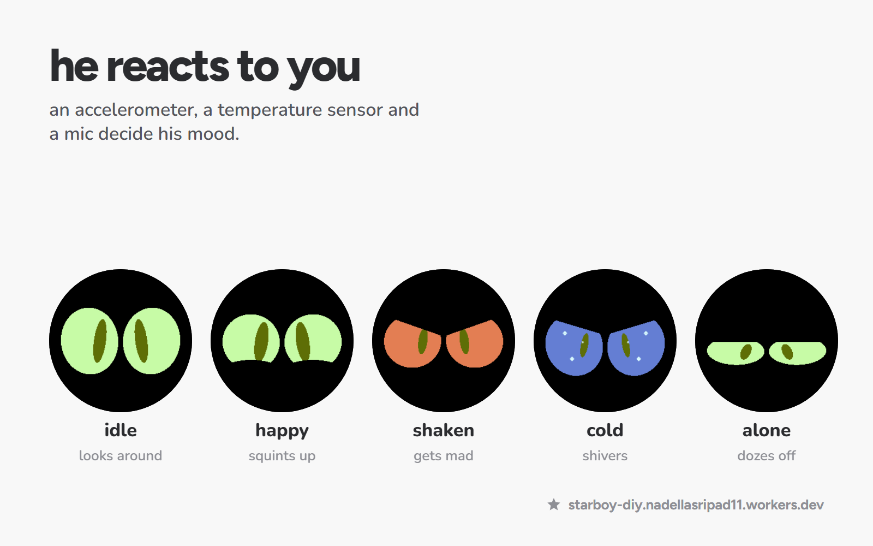
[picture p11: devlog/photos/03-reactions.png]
reactions


the firmware is a state machine. shake him for a second and he spins dizzy, then gets grumpy. below 10°c he turns icy blue and shivers. a loud sound makes him jump and dart his eyes around. after 25 seconds alone he dozes, after 75 he's fully asleep and dreaming, and the backlight dims so the battery lasts longer.

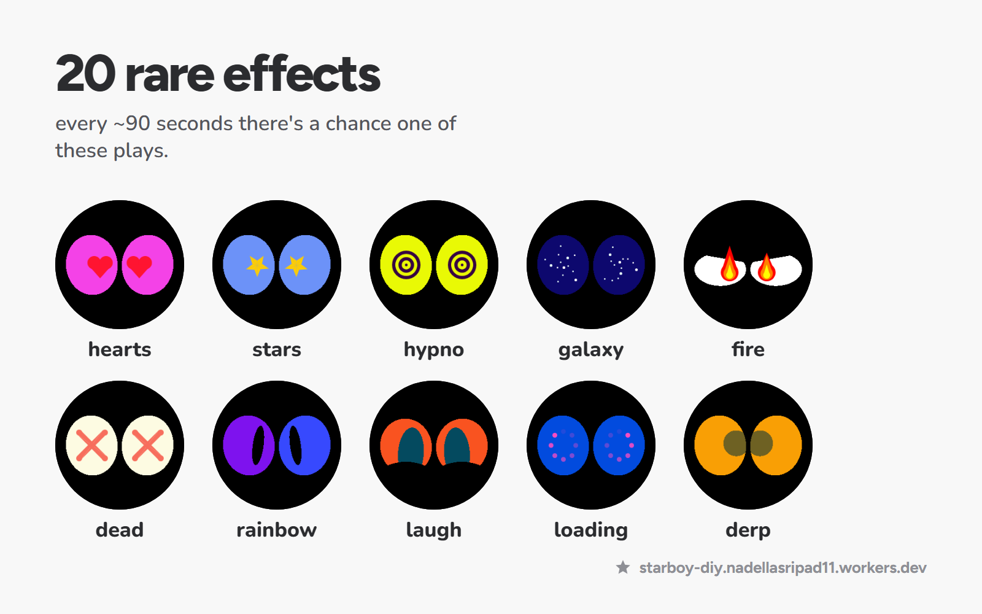
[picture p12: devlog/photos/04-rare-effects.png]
rare effects


and every ~90 seconds there's a chance he plays one of 20 rare effects: heart eyes, spinning stars, hypno rings, a galaxy, fire, X eyes and more.

## wiring

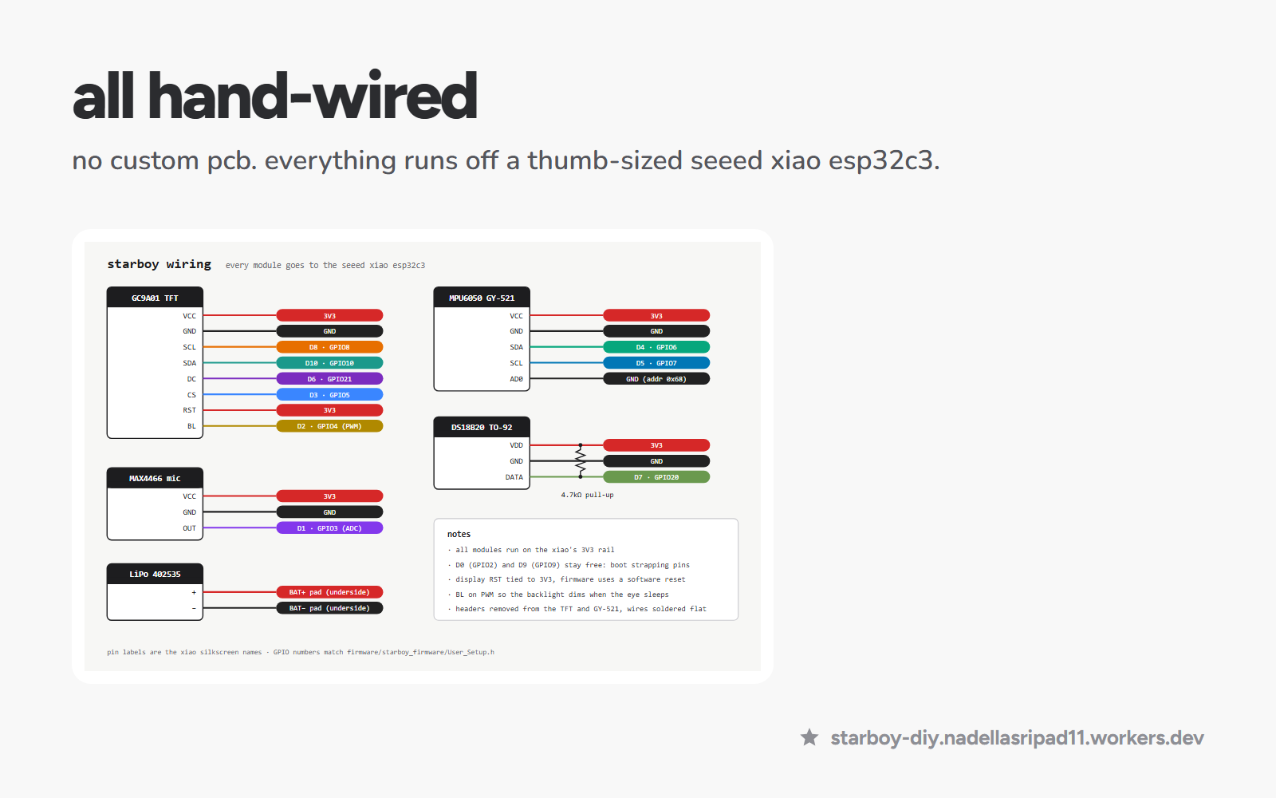
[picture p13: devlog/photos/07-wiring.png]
wiring


there's no custom pcb. everything is hand-wired to a seeed xiao esp32c3 with thin 30awg silicone wire, because that's the only way it all folds into the shell. the xiao also has a battery charger built in, so he charges over usb-c through a cutout in the side.

## parts

i first planned to order everything from aliexpress, but shipping takes 15–40 days, so i moved every part to amazon instead. most parts come in multi-packs, so i'm building two.

## a website you can play with

i built a site where the eyes follow your cursor and you can trigger every reaction and rare effect. it runs the same eye code as the real firmware:
**[starboy-diy.nadellasripad11.workers.dev](https://starboy-diy.nadellasripad11.workers.dev/)**

## what's next

- parts arrive, then i print the shell in petg and paint it chrome
- solder everything and flash the firmware onto the real screen for the first time
- tune the sensor thresholds so he reacts at the right moments
- post the first video of him actually alive 👀

follow along if you want to see him wake up for the first time.

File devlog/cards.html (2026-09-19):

# starboy diy

a tiny wearable pet i'm building from scratch. he lives on your belt loop and reacts to you.

round 1.28" screen for a face

motion, temperature + sound sensors

400 eye looks, each with a rarity

designed + built from scratch

## 4 eye shapes

every star rolls one the first time he boots up, and keeps it forever.

## he reacts to you

an accelerometer, a temperature sensor and a mic decide his mood.

## 20 rare effects

every ~90 seconds there's a chance one of these plays.

## the shell

designed in openscad · 65 × 64 × 20.5 mm · printed in petg, then chromed



the eye sits in a stepped screen pocket



front + keyring



engraved back medallion

## 100 colorways × 4 shapes

400 looks total. the rarest ones show up 0.04% of the time.

## all hand-wired

no custom pcb. everything runs off a thumb-sized seeed xiao esp32c3.



## sensor sandbox

be his sensors on the website. same mood logic as the real firmware.

shivering

temperature2°c

noisequiet

tiltflat

hold to shake

chilly · below 10°c → shivering · below 5°c

## 3 bugs caught before the parts arrived

i wrote tests for his mood logic with a fake clock. they found these.

→

shaking froze his eyes

the dizzy spin never played while you were still shaking him.

fixed: he spins now

→

a belt loop = tilted forever

hanging upright read as 90° tilt, so he'd never sleep and drain the battery.

fixed: he gets used to it

→

asleep and deaf

my battery saver meant he only listened 3% of the time while sleeping.

fixed: a clap wakes him

22mood tests5eye seed tests310firmware ↔ website checks

## pick his eyes

tap any of the 400 looks on the site and get the exact seed that gives a real star those eyes.

cat starlight

0.17% · rare

type this in the star's serial console:

seed 1da79c35copy

## tuning console + hardware test

tune him over usb without reflashing, and test every part before closing the shell.

> fake temp 2 fake temp 2.0C > mood shiver -> shiver > set loud 900 tune shake 16.0 | cold 10.0 | loud 900 | doze 25s ... live now. type `save` to keep it after a restart > fx fire -> fire > reroll Eye seed: 0x1DA79C35 | cat starlight

example session · the firmware compiles, parts are on the way

screen red, green, blue, white fills

backlight fades out and back in

i2c finds the motion sensor

mpu6050 reads ~9.8 m/s² of gravity

ds18b20 reads the air temperature

mic idles near the middle, bars move on a clap

starboy-diy.nadellasripad11.workers.dev

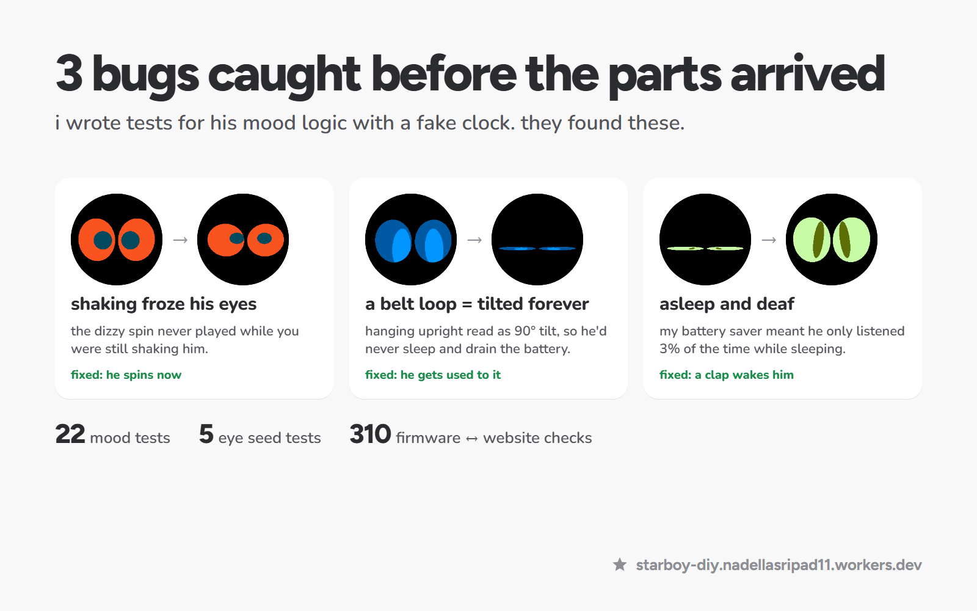
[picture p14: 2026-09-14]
devlog/photos/devlog3/2-bugs-caught.png

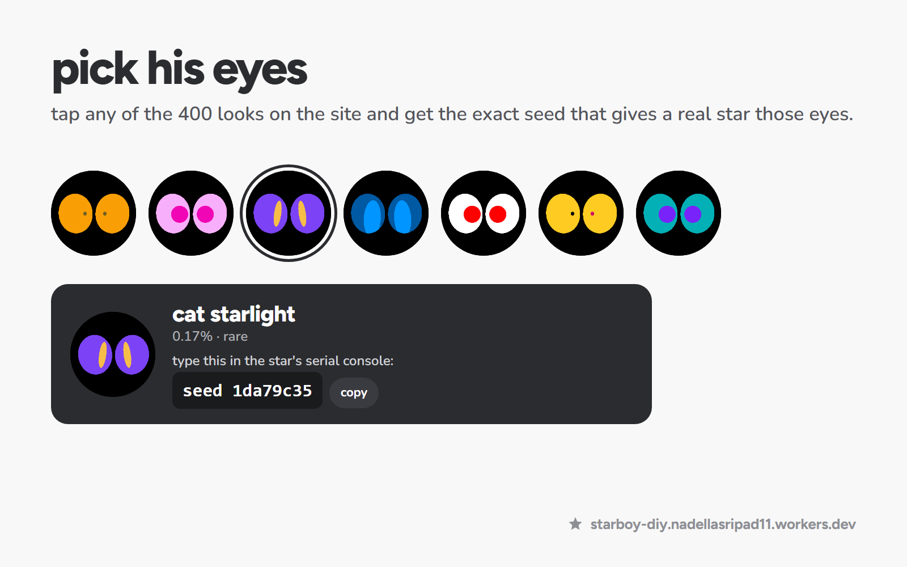
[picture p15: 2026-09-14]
devlog/photos/devlog3/3-pick-his-eyes.png

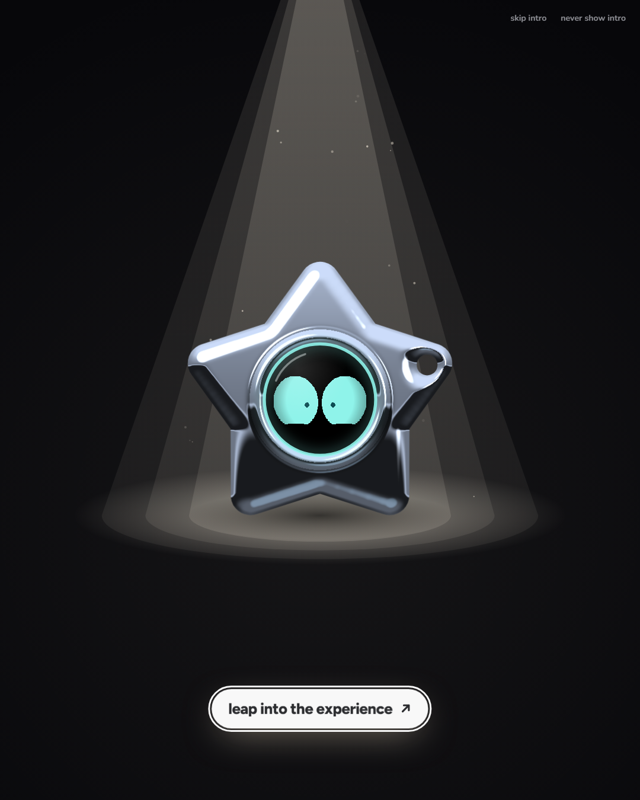
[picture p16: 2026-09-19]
devlog/photos/devlog4_intro.png

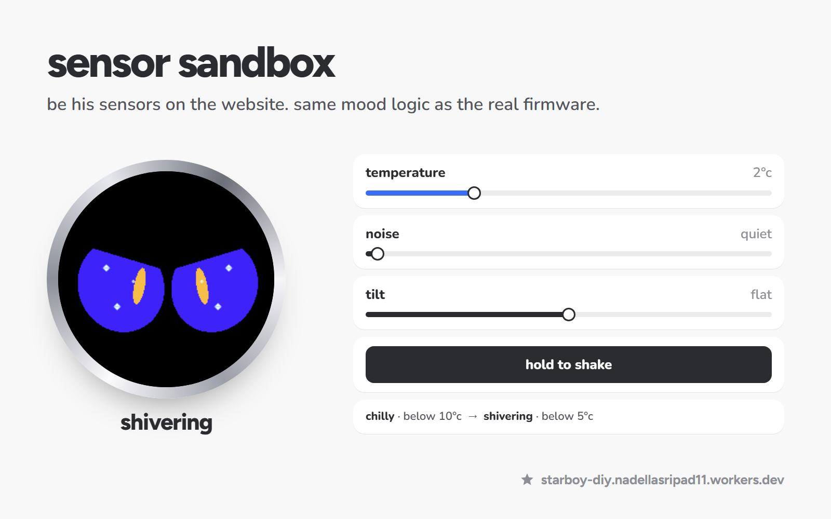
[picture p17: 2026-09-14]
devlog/photos/devlog3/1-sensor-sandbox.png

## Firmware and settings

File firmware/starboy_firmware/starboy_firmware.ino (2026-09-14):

// ============================================================
// STARBOY DIY — Complete Eye Firmware  v2.0
// ============================================================
// 500+ animations | 100 colorways × 4 eye shapes
// Unofficial fan build, inspired by Creature's starboy (lilguy.net). Not affiliated.
// Behaviors: idle · blink · curious · happy · bored · alert
//   suspicious · dizzy · angry · cold/shiver · loud/anxious
//   tilt-tracking · doze · sleep · 20 rare special effects
//
// Hardware:
//   Seeed XIAO ESP32C3 (built-in LiPo charger; EEMB 402535 320mAh on BAT pads)
//   GC9A01 1.28" Round TFT (240×240) — SPI: SCK D8, MOSI D10, CS D3, DC D6
//   Backlight — PWM on D2 (GPIO4)
//   MPU6050 Accelerometer/Gyro — I2C (SDA=D4/GPIO6, SCL=D5/GPIO7)
//   DS18B20 Temperature — OneWire (D7/GPIO20, 4.7kΩ to 3.3V)
//   MAX4466 Mic — Analog (D1/GPIO3)
//
// Libraries (Arduino Library Manager):
//   TFT_eSPI by Bodmer        ← ALSO copy User_Setup.h to library folder!
//   Adafruit MPU6050
//   Adafruit Unified Sensor
//   DallasTemperature
//   OneWire
//
// Board settings: XIAO_ESP32C3 · USB CDC On Boot: Enabled
// ============================================================

#include <TFT_eSPI.h>
#include <Wire.h>
#include <Adafruit_MPU6050.h>
#include <Adafruit_Sensor.h>
#include <OneWire.h>
#include <DallasTemperature.h>
#include <Preferences.h>
#include <math.h>

// ─── Pins ────────────────────────────────────────────────
// TFT pins defined in User_Setup.h
// Pins are for the Seeed XIAO ESP32C3 (built-in LiPo charger). Inputs are
// kept off the strapping pins GPIO2/8/9; GPIO8 is only used as SPI clock,
// which is what the XIAO routes it for.
#define ONE_WIRE_BUS  20      // D7  — DS18B20 data
#define MIC_PIN       3       // D1  — ADC1_CH3, MAX4466 OUT
#define HAS_MIC       true    // set false to disable mic checks

// Display backlight on a PWM pin so sleep can actually dim it. Wire the
// module's BL pin HERE, not to 3.3V — tied to 3.3V it's full brightness
// forever, even with the eyes shut, and the battery lasts a few hours.
#define BL_PIN        4       // D2
#define BL_PWM_FREQ   5000
#define BL_PWM_BITS   8
#define BL_CH         0       // only used on ESP32 Arduino core 2.x
#define BL_AWAKE      255
#define BL_DOZE       70
#define BL_SLEEP      10
#define DEBUG_SENSORS 0       // 1 = print shake / temp / sound once a second for tuning

// ─── Display ─────────────────────────────────────────────
TFT_eSPI    tft;
TFT_eSprite spr(&tft);        // off-screen sprite — zero flicker
bool        sprOK = false;

#define W  240
#define H  240
#define CX 120
#define CY 120

// ─── Sensors ─────────────────────────────────────────────
Adafruit_MPU6050  mpu;
bool              mpuOK = false;
OneWire           oneWire(ONE_WIRE_BUS);
DallasTemperature ds18b20(&oneWire);
Preferences       prefs;

// ─── Eye design: 100 colorways × 4 shapes ────────────────
// Eye style, colours and odds are based on Creature's public eye gallery; the
// colorway names are our own. Each eye is a flat block of colour on
// black with a pupil in a second colour. The rarest colorways give the two
// eyes different pupils. weight = how often a colorway gets rolled.
struct Colorway { const char *name; uint32_t body, pupL, pupR; uint8_t weight; };
const Colorway COLORWAYS[100] = {
  { "tangerine",    0xF99F05, 0x6E6123, 0x6E6123, 10 },
  { "pistachio",    0xC7FBA6, 0x5E6E06, 0x5E6E06, 10 },
  { "fern",         0x039442, 0x71FF6F, 0x71FF6F, 10 },
  { "lagoon",       0x6FF5D0, 0x106E54, 0x106E54, 10 },
  { "deepsea",      0x0059A3, 0x0095FF, 0x0095FF, 10 },
  { "cricket",      0x42DE86, 0x436A16, 0x436A16, 10 },
  { "chambray",     0x6C92F8, 0x102A6E, 0x102A6E, 10 },
  { "orchid",       0xF8AFFB, 0xF006B4, 0xF006B4, 10 },
  { "raspberry",    0xA10180, 0xFC609C, 0xFC609C, 10 },
  { "grapefruit",   0xF6759F, 0x56031F, 0x56031F, 10 },
  { "ruby",         0xAE0002, 0xFF5252, 0xFF5252, 10 },
  { "slate",        0x645252, 0xA4A4A4, 0xA4A4A4, 10 },
  { "fuchsia",      0xDD06CB, 0x7B1612, 0x7B1612, 10 },
  { "violet",       0x7260E6, 0x622058, 0x622058, 10 },
  { "firetruck",    0xF20F07, 0xFFFFFF, 0xFFFFFF,  8 },
  { "clover",       0x59BF05, 0xFFFFFF, 0xFFFFFF,  8 },
  { "skyline",      0x05A8F9, 0xFCEEEE, 0xFCEEEE,  8 },
  { "midnight",     0x4028FF, 0xEBFFFC, 0xEBFFFC,  8 },
  { "confetti",     0xF442E7, 0xFFFFFF, 0xFFFFFF,  8 },
  { "frost",        0xFBFBFB, 0x167B61, 0x167B61,  9 },
  { "redeye",       0xFFFFFF, 0xFF0000, 0xFF0000,  9 },
  { "cloud",        0xFFFFFF, 0x5A79F3, 0x5A79F3,  9 },
  { "yogurt",       0xFFECE0, 0xCE0959, 0xCE0959,  9 },
  { "apricot",      0xFDFBE2, 0xF76E5D, 0xF76E5D,  9 },
  { "sunbeam",      0xE0F4FB, 0xDE9109, 0xDE9109,  9 },
  { "porcelain",    0xFCD9CF, 0x070571, 0x070571,  9 },
  { "lavender",     0xE1BFE1, 0x2722DB, 0x2722DB,  9 },
  { "lemonade",     0xF9FFB2, 0xCA00CA, 0xCA00CA,  9 },
  { "mojito",       0xEAFCC5, 0x09B6CE, 0x09B6CE,  9 },
  { "butter",       0xF6E5A5, 0x0D73F7, 0x0D73F7,  9 },
  { "peppermint",   0x9CFBD5, 0x790C05, 0x790C05,  9 },
  { "beetle",       0xC3110E, 0x000000, 0x000000,  7 },
  { "olive",        0x8BD67C, 0x230606, 0x230606,  7 },
  { "abyss",        0x0F7BA9, 0x000000, 0x000000,  7 },
  { "amethyst",     0xE202E8, 0x0A0A0A, 0x0A0A0A,  7 },
  { "classic",      0xFFFFFF, 0x000000, 0x000000,  7 },
  { "coral",        0xF95320, 0x044A5F, 0x044A5F,  3 },
  { "halloween",    0xE87102, 0x55FC6E, 0x55FC6E,  3 },
  { "citrus",       0xF6FD21, 0x1C9DE3, 0x1C9DE3,  3 },
  { "radioactive",  0xE9F905, 0x360342, 0x360342,  3 },
  { "electric",     0xC4F41D, 0x530AEC, 0x530AEC,  3 },
  { "neon",         0x95F124, 0xF50DCF, 0xF50DCF,  3 },
  { "parrot",       0x55F927, 0x9F7717, 0x9F7717,  3 },
  { "venus",        0x15F817, 0x5E045E, 0x5E045E,  3 },
  { "emerald",      0x14DA70, 0x3516AF, 0x3516AF,  3 },
  { "dusk",         0xAE2400, 0xF855FC, 0xF855FC,  3 },
  { "bluebird",     0x15ABF8, 0x5E2304, 0x5E2304,  3 },
  { "disco",        0x024BDE, 0xFB4CC3, 0xFB4CC3,  3 },
  { "starlight",    0x7B43F5, 0xF6BD49, 0xF6BD49,  3 },
  { "radar",        0x126487, 0x2EE605, 0x2EE605,  3 },
  { "papaya",       0x84FB8E, 0xF64982, 0xF64982,  3 },
  { "uv",           0x6922F0, 0xA3F410, 0xA3F410,  3 },
  { "bubblewrap",   0xF474DC, 0xE8FCA6, 0xE8FCA6,  3 },
  { "grape",        0x7202FC, 0xFDB0CE, 0xFDB0CE,  3 },
  { "firefly",      0x7768FE, 0x55FC87, 0x55FC87,  3 },
  { "magenta",      0xD602E8, 0xFBF823, 0xFBF823,  3 },
  { "forest",       0x1E6935, 0xFC7AC0, 0xFC7AC0,  3 },
  { "tropic",       0x018335, 0x23FAFB, 0x23FAFB,  3 },
  { "alien",        0xF40DF8, 0x19F515, 0x19F515,  3 },
  { "wintergreen",  0x9CFBCE, 0x790572, 0x790572,  3 },
  { "arcade",       0xFA486F, 0x92FABE, 0x92FABE,  3 },
  { "harbor",       0x14ABD6, 0xEEFA24, 0xEEFA24,  3 },
  { "snowcone",     0xC206AD, 0x49F6D9, 0x49F6D9,  3 },
  { "alarm",        0xFD0C0D, 0x2905E6, 0x2905E6,  3 },
  { "heatwave",     0x994400, 0x00EEFF, 0x00EEFF,  3 },
  { "bruise",       0xB60080, 0x429EFB, 0x429EFB,  3 },
  { "iceberg",      0x71FEAE, 0x5598FC, 0x5598FC,  3 },
  { "pitaya",       0xB60053, 0xCFFA0F, 0xCFFA0F,  3 },
  { "rosehip",      0xB6003C, 0x05E605, 0x05E605,  3 },
  { "beet",         0xC5013C, 0x09CE93, 0x09CE93,  3 },
  { "wax",          0x973849, 0xF7FBBC, 0xF7FBBC,  3 },
  { "pixel",        0x737373, 0x09E151, 0x09E151,  3 },
  { "chime",        0xBEBEBE, 0xE42D06, 0xE42D06,  3 },
  { "letter",       0xBE6A6A, 0x76D8EB, 0x76D8EB,  5 },
  { "terracotta",   0xCC6262, 0x3E4002, 0x3E4002,  5 },
  { "fruitpunch",   0xF6826C, 0x95059B, 0x95059B,  5 },
  { "duckpond",     0x7B8401, 0x0737A7, 0x0737A7,  5 },
  { "ketchup",      0x60A611, 0xB4040F, 0xB4040F,  5 },
  { "honey",        0x509156, 0xF4C524, 0xF4C524,  5 },
  { "mermaid",      0x02B0B6, 0x7923FB, 0x7923FB,  5 },
  { "sandcastle",   0xB8804A, 0xF7F574, 0xF7F574,  5 },
  { "balloon",      0x7DB5F4, 0xC10787, 0xC10787,  5 },
  { "swamp",        0xA7AFF6, 0x837605, 0x837605,  5 },
  { "dustbunny",    0xEC75F6, 0x564803, 0x564803,  5 },
  { "sakura",       0xFCB7F2, 0x069A1E, 0x069A1E,  5 },
  { "riverbank",    0xFCB7C3, 0x068F9A, 0x068F9A,  5 },
  { "tv",           0x666666, 0x000000, 0xFFFFFF,  2 },
  { "pencil",       0x666666, 0xFFEDED, 0x000000,  2 },
  { "pinwheel",     0xB60207, 0xD2F9F9, 0x60D105,  2 },
  { "argyle",       0xB865A8, 0x76D8EB, 0x8F1716,  2 },
  { "carp",         0xFE6873, 0x0A0A0A, 0xD0F910,  2 },
  { "pearl",        0xD1D9FA, 0xC11207, 0xD20ADF,  2 },
  { "traffic",      0x34F7FD, 0x038C03, 0xF91024,  2 },
  { "wasp",         0xFDCB21, 0x0A0A0A, 0xD10566,  2 },
  { "pond",         0xD1F63B, 0x10812B, 0x0F91F4,  2 },
  { "movie",        0xEAF66E, 0xBB240A, 0x0964E7,  2 },
  { "tricolor",     0xF6EAB9, 0x177E39, 0x2722DB,  2 },
  { "parasol",      0xE7E3E9, 0xF65F28, 0x4F6BF8,  2 },
  { "gelato",       0xE4F4E2, 0x4A0A99, 0xDB8405,  2 },
  { "triple",       0x87493B, 0xEB76DD, 0xB7ABF3,  2 },
};

enum EyeShape : uint8_t { SHAPE_DOT = 0, SHAPE_CIRCLE, SHAPE_CAT, SHAPE_ACORN };
const char   *SHAPE_NAMES[4]  = { "dot", "circle", "cat", "acorn" };
const uint8_t SHAPE_WEIGHT[4] = { 10, 40, 30, 20 };   // percent

inline uint16_t rgb565(uint32_t c) {
  return ((c >> 16 & 0xF8) << 8) | ((c >> 8 & 0xFC) << 3) | ((c & 0xFF) >> 3);
}

// ─── Eye design (seed-based, unique per unit) ────────────
uint32_t eyeSeed;
uint8_t  d_colorway;
uint8_t  d_shape;
uint16_t d_irisC;     // eye body
uint16_t d_pupilC;    // left pupil
uint16_t d_pupilC2;   // right pupil

// ─── Eye geometry ────────────────────────────────────────
// Two big ovals almost touching, filling most of the round display.
#define EYE_L_X   (CX - 52)
#define EYE_R_X   (CX + 52)
#define EYE_Y     CY
#define IRIS_RX   48
#define IRIS_RY   56
#define EYE_TILT  0.10f   // radians; the top of each eye leans outward

// ─── Animation expression table (50 base targets) ───────
// Each entry: gazeX, gazeY, blinkT, pupilR%, irisRx%, irisRy%,
//             browInnerL, browInnerR, browY
// 500+ total animations = these 50 × 8 parametric variants each
//   + 20 rare specials + ~70 named transition sequences
struct ExprDef { int8_t gx,gy; uint8_t bl,pr,ix,iy; int8_t bwl,bwr,bwy; };
const ExprDef EXPR[50] PROGMEM = {
// gx  gy  bl  pr  ix  iy  bwL  bwR bwY
 {  0,  0,  0,100,100,100,   0,   0,  0 }, // 00 neutral
 {  0, -2,  8,110,100, 90,  -3,  -3, -2 }, // 01 happy
 {  2, -3,  0,115,100,100,   2,   2, -4 }, // 02 curious
 {  0,  3, 30, 90,100, 85,   0,   0,  3 }, // 03 bored
 {  0,  0,  0,125,105,105,   5,   5, -3 }, // 04 startled/alert
 { -4,  0, 15, 85,100, 90,  -2,   2,  1 }, // 05 suspicious
 {  0,  0, 50, 85,100, 85,   8,   8,  2 }, // 06 annoyed
 {  0,  0, 60, 75,100, 80,  14,  14,  4 }, // 07 angry
 {  0,  0, 70, 65,100, 75,  20,  20,  6 }, // 08 rage
 {  0,  0, 40, 90,110, 80,   4,   4,  0 }, // 09 squinting
 {  0, -1, 20,100,100, 95,  -1,  -1, -1 }, // 10 content/peaceful
 {  3,  2,  0,100,100,100,   0,   0,  0 }, // 11 glance right
 { -3,  2,  0,100,100,100,   0,   0,  0 }, // 12 glance left
 {  0, -4,  0,100,100,100,   0,   0,  0 }, // 13 look up
 {  0,  4,  5, 95,100, 97,   0,   0,  0 }, // 14 look down
 {  0,  0, 90, 90,100, 90,   0,   0,  3 }, // 15 nearly closed
 {  0,  0,100, 90,100, 90,   0,   0,  3 }, // 16 fully closed
 {  2, -2,  0,120,110,100,   3,   0, -2 }, // 17 smug R
 { -2, -2,  0,120,110,100,   0,   3, -2 }, // 18 smug L
 {  0,  0, 35, 70, 90,120,   6,   6,  2 }, // 19 tired squint
 {  0, -1, 10,130,105, 90,  -2,  -2, -3 }, // 20 excited
 { -3, -1,  0, 70, 85,110,   3,  -1,  0 }, // 21 shifty L
 {  3, -1,  0, 70, 85,110,  -1,   3,  0 }, // 22 shifty R
 {  0,  0, 45, 60,100,120,  12,  12,  5 }, // 23 squint hard
 {  0,  2, 55, 95,100, 80,   0,   0,  4 }, // 24 drowsy
 {  0,  3, 70, 90,100, 75,   0,   0,  5 }, // 25 very drowsy
 {  0,  0, 15, 95, 95, 95,  -2,  -2, -1 }, // 26 gentle/soft
 {  0, -3,  5,105,100,105,  -1,  -1, -4 }, // 27 wondering
 {  0,  0, 30, 80, 90, 90,  10,  10,  3 }, // 28 unamused
 {  1, -1, 10,110,100,100,   2,  -2, -2 }, // 29 playful
 {  0,  0,  0,140,110,100,  -3,  -3, -5 }, // 30 shocked wide
 {  0,  0, 10, 60, 85,115,   5,   5,  0 }, // 31 narrow suspicious
 {  0, -1, 25,105,100, 92,  -1,  -1,  0 }, // 32 relaxed happy
 {  0,  1, 40, 85,100, 88,   7,   7,  2 }, // 33 mildly irritated
 {  0,  0,  0,100,115,115,   0,   0, -1 }, // 34 round cute
 {  5,  0,  0,100, 70,120,   0,   0,  0 }, // 35 extreme look R
 { -5,  0,  0,100, 70,120,   0,   0,  0 }, // 36 extreme look L
 {  0,  0, 50, 50, 80,130,  10,  10,  4 }, // 37 slit/cat eyes
 {  0, -2, 20,115,105, 95,   0,   0, -3 }, // 38 warm happy
 {  0,  0, 65, 70, 95, 90,  15,  15,  6 }, // 39 seething
 {  2,  2, 20, 90,100, 95,   1,   0,  1 }, // 40 glance relax R
 { -2,  2, 20, 90,100, 95,   0,   1,  1 }, // 41 glance relax L
 {  0,  0, 10,125,110,105,  -4,  -4, -4 }, // 42 wide surprised
 {  0,  0, 80, 85,100, 82,   0,   0,  6 }, // 43 barely open
 {  0,  0,100, 90,100, 85,   0,   0,  4 }, // 44 dreaming sleep
 {  0, -1,  5,100,105,105,   0,   0, -2 }, // 45 just woke
 {  0, -2,  0,100,110, 95,  -1,  -1, -2 }, // 46 bright cheerful
 {  4, -4,  0,110,100,100,   0,   0, -1 }, // 47 noticing R
 { -4, -4,  0,110,100,100,   0,   0, -1 }, // 48 noticing L
 {  0,  0, 55, 55, 70,150,  12,  12,  6 }, // 49 horizontal slit angry
};

// ─── Eye rendering state ─────────────────────────────────
struct EyeState {
  float gx, gy;          // gaze offset
  float blinkT;          // top lid (0=open 1=closed)
  float blinkB;          // bottom lid
  float pupR;            // pupil scale (1.0=normal)
  float irX, irY;        // iris x/y scale
  float bwL, bwR;        // brow inner end offset px
  float bwY;             // brow height offset
  float smile;           // bottom lid pushed up in a curve (0-1)
  float colMix;          // 0=design 1=override
  uint16_t colOvr;       // color override
  uint8_t  fx;           // special effect 0=none
  float    fxP;          // effect phase/param
};
EyeState eye, eyeT;      // current + target
float    baseGx = 0, baseGy = 0;            // gaze of the current expression; glances start here
uint32_t lastSaccade = 0, nextSaccade = 2000;

// Helper — load expression into target
void setTarget(uint8_t idx) {
  ExprDef e;
  memcpy_P(&e, &EXPR[idx], sizeof(ExprDef));
  eyeT.gx   = e.gx;  eyeT.gy   = e.gy;
  eyeT.blinkT = e.bl / 100.0f;  eyeT.blinkB = eyeT.blinkT * 0.45f;
  eyeT.pupR  = e.pr / 100.0f;
  eyeT.irX   = e.ix / 100.0f;   eyeT.irY   = e.iy / 100.0f;
  eyeT.bwL   = e.bwl; eyeT.bwR  = e.bwr; eyeT.bwY  = e.bwy;
  eyeT.colMix = 0; eyeT.fx = 0;
  baseGx = eyeT.gx; baseGy = eyeT.gy;
  switch (idx) {   // happy faces squint up from below
    case 1: case 38: eyeT.smile = 0.8f; break;
    case 20: case 46: eyeT.smile = 0.6f; break;
    case 32:         eyeT.smile = 0.5f; break;
    case 10:         eyeT.smile = 0.3f; break;
    default:         eyeT.smile = 0.0f; break;
  }
}

// ─── State machine ───────────────────────────────────────
enum StarState : uint8_t {
  S_IDLE=0, S_CURIOUS, S_HAPPY, S_BORED, S_ALERT,
  S_SUSPICIOUS, S_BLINK,
  S_DIZZY_MILD, S_DIZZY_SEVERE, S_RECOVERING,
  S_ANGRY, S_SEETHING,
  S_CHILL, S_SHIVER, S_FREEZE,
  S_STARTLED, S_ANXIOUS, S_OVERWHELMED,
  S_TILT,
  S_DOZE, S_MICROSLEEP, S_SLEEP, S_DREAMING,
  // Rare specials
  S_RARE_RAINBOW, S_RARE_HEARTS, S_RARE_STARS,
  S_RARE_GLITCH, S_RARE_MATRIX, S_RARE_SPIRAL,
  S_RARE_LOADING, S_RARE_ERROR, S_RARE_DERP,
  S_RARE_SMUG, S_RARE_CRY, S_RARE_LAUGH,
  S_RARE_SHOCKED, S_RARE_DEAD, S_RARE_GALAXY,
  S_RARE_HEARTBEAT, S_RARE_FIRE, S_RARE_HYPNO,
  S_RARE_STARFIELD, S_RARE_GLITCH2,
  S_COUNT
};

StarState  curState = S_IDLE;
uint32_t   stateMs  = 0;
uint32_t   lastInteract = 0;
uint32_t   lastBlink = 0;
uint32_t   nextBlink = 0;
uint32_t   lastGazeShift = 0;
uint32_t   nextGazeShift = 0;
uint32_t   lastTempRead = 0;
uint32_t   lastRareCheck = 0;
uint32_t   lastSpecialIdle = 0;
uint8_t    blinkPhase = 0;   // 0=open 1=closing 2=open
uint32_t   blinkPhaseMs = 0;
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
void loop() {
  uint32_t now = millis();
  static uint32_t lastFrame = 0;
  frameScale = lastFrame ? constrain((now - lastFrame) / 33.33f, 0.25f, 8.0f) : 1.0f;
  lastFrame = now;

  handleSerial();
  readSensors();
  updateState();
  updateInterp();
  updateBacklight();
  drawFrame();

  // 30fps awake. Dozing and sleeping eyes barely move, so drop to 15 / 8 fps
  // and let the CPU idle in delay() instead of pushing frames over SPI.
  uint32_t frameMs = (curState == S_SLEEP || curState == S_DREAMING) ? 125
                   : (curState == S_DOZE) ? 66 : 33;
  // Keep listening while we wait. At 8fps one short mic burst per frame hears
  // only ~3% of the time, so a clap could slip past a sleeping star.
  while (millis() - now < frameMs) {
    if (HAS_MIC) listenMic();
    delay(8);
  }
}

// ════════════════════════════════════════════════════════
// EYE DESIGN INIT
// ════════════════════════════════════════════════════════
void initEyeDesign() {
  prefs.begin("starboy", false);
  eyeSeed = prefs.getUInt("seed", 0);
  if (eyeSeed == 0) {
    eyeSeed = (uint32_t)esp_random();
    if (eyeSeed == 0) eyeSeed = 0xDEADBEEF;
    prefs.putUInt("seed", eyeSeed);
  }
  prefs.end();

  uint32_t s = eyeSeed;
  auto rnd = [&](uint16_t n) -> uint16_t {
    s = s * 1664525u + 1013904223u;
    return (uint16_t)((s >> 8) % n);
  };

  uint16_t total = 0;
  for (int i = 0; i < 100; i++) total += COLORWAYS[i].weight;
  uint16_t pick = rnd(total);
  d_colorway = 99;
  for (int i = 0; i < 100; i++) {
    if (pick < COLORWAYS[i].weight) { d_colorway = i; break; }
    pick -= COLORWAYS[i].weight;
  }

  pick = rnd(100);
  d_shape = SHAPE_ACORN;
  for (int i = 0; i < 4; i++) {
    if (pick < SHAPE_WEIGHT[i]) { d_shape = i; break; }
    pick -= SHAPE_WEIGHT[i];
  }

  const Colorway &cw = COLORWAYS[d_colorway];
  d_irisC   = rgb565(cw.body);
  d_pupilC  = rgb565(cw.pupL);
  d_pupilC2 = rgb565(cw.pupR);

  Serial.printf("Eye seed: 0x%08X | %s %s | colorway %.1f%% | shape %u%%\n",
                eyeSeed, SHAPE_NAMES[d_shape], cw.name,
                100.0f * cw.weight / total, SHAPE_WEIGHT[d_shape]);
}

// ════════════════════════════════════════════════════════
// SENSOR READING
// ════════════════════════════════════════════════════════
// Short mic burst between frames. Attack only: the per-frame decay in
// readSensors() still decides how fast the level falls.
void listenMic() {
  int lo = 4095, hi = 0;
  for (int i = 0; i < 16; i++) {
    int raw = analogRead(MIC_PIN);
    if (raw < lo) lo = raw;
    if (raw > hi) hi = raw;
  }
  if (hi - lo > soundPeak) soundPeak = hi - lo;
}

void readSensors() {
  uint32_t now = millis();

  // MPU6050
  if (mpuOK) {
    sensors_event_t a, g, temp;
    mpu.getEvent(&a, &g, &temp);
    accelX = a.acceleration.x;
    accelY = a.acceleration.y;
    accelZ = a.acceleration.z;

    float mag = sqrtf(accelX*accelX + accelY*accelY + accelZ*accelZ);
    float instant = fabsf(mag - 9.81f);
    shakeE += (instant - shakeE) * (1.0f - powf(0.85f, frameScale));  // smooth, frame-rate independent

    static uint32_t lastTiltMs = 0;
    float dt = lastTiltMs ? (float)(now - lastTiltMs) : 0.0f;
    lastTiltMs = now;
    if (!restInit) {
      restX = accelX; restY = accelY; restZ = accelZ;
      restInit = true;
    } else if (shakeE < 3.0f) {          // a shake shouldn't teach a new resting pose
      float k = min(1.0f, dt / TILT_REST_TAU_MS);
      restX += (accelX - restX) * k;
      restY += (accelY - restY) * k;
      restZ += (accelZ - restZ) * k;
    }
    float restMag = sqrtf(restX*restX + restY*restY + restZ*restZ);
    float cosLean = (accelX*restX + accelY*restY + accelZ*restZ) / max(0.001f, mag * restMag);
    tiltLean = acosf(constrain(cosLean, -1.0f, 1.0f)) * 180.0f / PI;
    float scale = mag / max(0.001f, restMag);
    tiltDX = accelX - restX * scale;
    tiltDY = accelY - restY * scale;

    if (shakeE > SHAKE_ON_G) {
      if (shakeStart == 0) shakeStart = now;
    } else {
      shakeStart = 0;
    }
  }

  // Temperature — non-blocking. The old blocking requestTemperatures() froze
  // the animation for ~190ms every 5s. Now: request, keep animating, read
  // once the conversion has had time to finish.
  static bool     tempPending = false;
  static uint32_t tempReqMs   = 0;
  if (!tempPending && now - lastTempRead > 5000) {
    ds18b20.requestTemperatures();
    tempPending = true;
    tempReqMs   = now;
  } else if (tempPending && now - tempReqMs >= 200) {   // 10-bit conversion ≈ 188ms
    tempPending  = false;
    lastTempRead = now;
    float t = ds18b20.getTempCByIndex(0);
    // 85.0 is the sensor's power-on value — it means no conversion happened
    if (t != DEVICE_DISCONNECTED_C && t != 85.0f && t > -50 && t < 100)
      ambientTemp = t + tune.tempOffsetC;
  }

  // Mic — peak-to-peak over a short burst. The MAX4466 output sits at
  // mid-rail (~2048) in silence, so the raw value made every room look loud
  // and the eye got stuck in "anxious". Max minus min over the burst is the
  // real sound level regardless of that offset. 32 samples ≈ a few ms.
  if (HAS_MIC) {
    int lo = 4095, hi = 0;
    for (int i = 0; i < 32; i++) {
      int raw = analogRead(MIC_PIN);
      if (raw < lo) lo = raw;
      if (raw > hi) hi = raw;
    }
    int p2p = hi - lo;
    if (p2p > soundPeak) soundPeak = p2p;                 // fast attack
    else soundPeak = (int)(soundPeak * powf(0.93f, frameScale));  // slow decay, same speed at any fps
  }

  applySensorOverrides();

  static uint32_t lastDbg = 0;
  if (debugSensors && now - lastDbg > 1000) {
    lastDbg = now;
    Serial.printf("shake %.1f  temp %.1fC  sound %d\n", shakeE, ambientTemp, soundPeak);
  }
}

// ════════════════════════════════════════════════════════
// STATE MACHINE
// ════════════════════════════════════════════════════════
void setState(StarState s) {
  if (curState == s) return;
  curState = s;
  stateMs  = millis();
  rarePhase = 0;
}
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

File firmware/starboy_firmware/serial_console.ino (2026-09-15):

// ============================================================
// Serial tuning console (115200 baud, newline line endings)
// ============================================================
// Lets you tune a real star without reflashing. Type `help` in the
// Arduino Serial Monitor.
//
//   status                 sensors, state, eyes and all tuning values
//   mood <name>            jump to a mood (idle, happy, dizzy, shiver, sleep...)
//   fx <name>              play a rare effect (hearts, fire, galaxy...)
//   reroll                 roll brand-new eyes and keep them
//   seed <hex>             set a specific eye seed
//   set <key> <value>      change a threshold live (shake, cold, loud, doze, sleep, rare)
//   save / defaults        write tuning to flash / restore factory values
//   fake temp <c>          pretend the air is this temperature
//   fake sound <p2p>       pretend the mic hears this level
//   fake off               go back to the real sensors
//   debug on|off           print sensor values every second
// ============================================================

struct NamedState { const char *name; StarState state; };

const NamedState MOODS[] = {
  { "idle", S_IDLE }, { "curious", S_CURIOUS }, { "happy", S_HAPPY }, { "bored", S_BORED },
  { "alert", S_ALERT }, { "suspicious", S_SUSPICIOUS }, { "dizzy", S_DIZZY_MILD },
  { "spin", S_DIZZY_SEVERE }, { "angry", S_ANGRY }, { "rage", S_SEETHING },
  { "chill", S_CHILL }, { "shiver", S_SHIVER }, { "freeze", S_FREEZE },
  { "startled", S_STARTLED }, { "anxious", S_ANXIOUS }, { "overwhelmed", S_OVERWHELMED },
  { "doze", S_DOZE }, { "sleep", S_SLEEP }, { "dream", S_DREAMING },
};

const NamedState RARES[] = {
  { "rainbow", S_RARE_RAINBOW }, { "hearts", S_RARE_HEARTS }, { "stars", S_RARE_STARS },
  { "glitch", S_RARE_GLITCH }, { "matrix", S_RARE_MATRIX }, { "spiral", S_RARE_SPIRAL },
  { "loading", S_RARE_LOADING }, { "error", S_RARE_ERROR }, { "derp", S_RARE_DERP },
  { "smug", S_RARE_SMUG }, { "cry", S_RARE_CRY }, { "laugh", S_RARE_LAUGH },
  { "shocked", S_RARE_SHOCKED }, { "dead", S_RARE_DEAD }, { "galaxy", S_RARE_GALAXY },
  { "heartbeat", S_RARE_HEARTBEAT }, { "fire", S_RARE_FIRE }, { "hypno", S_RARE_HYPNO },
  { "starfield", S_RARE_STARFIELD }, { "rgb", S_RARE_GLITCH2 },
};

// plain types in these signatures: the Arduino prototype generator places
// function declarations above this file's struct definitions
static const char *stateName(uint8_t s) {
  for (const auto &m : MOODS) if (m.state == s) return m.name;
  for (const auto &r : RARES) if (r.state == s) return r.name;
  return s == S_TILT ? "tilt" : s == S_RECOVERING ? "recovering" :
         s == S_MICROSLEEP ? "microsleep" : s == S_BLINK ? "blink" : "?";
}

// ─── tuning in flash ─────────────────────────────────────
void loadTuning() {
  prefs.begin("tune", true);
  tune.shakeOnG = prefs.getFloat("shake", tune.shakeOnG);
  tune.coldC    = prefs.getFloat("cold",  tune.coldC);
  tune.loudP2P  = prefs.getInt  ("loud",  tune.loudP2P);
  tune.dozeMs   = prefs.getUInt ("doze",  tune.dozeMs);
  tune.sleepMs  = prefs.getUInt ("sleep", tune.sleepMs);
  tune.rareMs   = prefs.getUInt ("rare",  tune.rareMs);
  tune.tempOffsetC = prefs.getFloat("toff", tune.tempOffsetC);
  prefs.end();
}

static void saveTuning() {
  prefs.begin("tune", false);
  prefs.putFloat("shake", tune.shakeOnG);
  prefs.putFloat("cold",  tune.coldC);
  prefs.putInt  ("loud",  tune.loudP2P);
  prefs.putUInt ("doze",  tune.dozeMs);
  prefs.putUInt ("sleep", tune.sleepMs);
  prefs.putUInt ("rare",  tune.rareMs);
  prefs.putFloat("toff",  tune.tempOffsetC);
  prefs.end();
}

// ─── sensor overrides for testing on the bench ───────────
static bool  fakeTempOn = false, fakeSoundOn = false;
static float fakeTempC = 20.0f;
static int   fakeSound = 0;

void applySensorOverrides() {
  if (fakeTempOn)  ambientTemp = fakeTempC;
  if (fakeSoundOn) soundPeak = fakeSound;
}

// ─── commands ────────────────────────────────────────────
static void printHelp() {
  Serial.println(F("commands: status | hw | demo | mood <name> | fx <name> | reroll | seed <hex>"));
  Serial.println(F("          set <shake|cold|loud|doze|sleep|rare|tempoffset> <value> | save | defaults"));
  Serial.println(F("          fake temp <c> | fake sound <p2p> | fake off | debug on|off"));
  Serial.print(F("moods: "));
  for (const auto &m : MOODS) { Serial.print(m.name); Serial.print(' '); }
  Serial.print(F("\nrare fx: "));
  for (const auto &r : RARES) { Serial.print(r.name); Serial.print(' '); }
  Serial.println();
}

static void printStatus() {
  const Colorway &cw = COLORWAYS[d_colorway];
  Serial.printf("state %s for %lus | idle %lus\n", stateName(curState),
                (unsigned long)((millis() - stateMs) / 1000), (unsigned long)((millis() - lastInteract) / 1000));
  Serial.printf("eyes  %s %s (seed 0x%08X)\n", SHAPE_NAMES[d_shape], cw.name, eyeSeed);
  Serial.printf("sense shake %.1f | temp %.1fC%s | sound %d%s | tilt %.0f deg from rest | mpu %s\n",
                shakeE, ambientTemp, fakeTempOn ? " (fake)" : "", soundPeak, fakeSoundOn ? " (fake)" : "",
                tiltLean, mpuOK ? "ok" : "missing");
  Serial.printf("tune  shake %.1f | cold %.1f | loud %d | doze %lus | sleep %lus | rare %lus | tempoffset %+.1f\n",
                tune.shakeOnG, tune.coldC, tune.loudP2P,
                (unsigned long)(tune.dozeMs / 1000), (unsigned long)(tune.sleepMs / 1000), (unsigned long)(tune.rareMs / 1000),
                tune.tempOffsetC);
}
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

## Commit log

2026-09-13 Initial commit: STARBOY DIY replica
    3D printable 5-point metallic star keychain with animated eye display.
    - hardware/starboy_star.scad: parametric OpenSCAD shell with engraved back
    - firmware/: ESP32-C3 Arduino firmware with 7 eye behaviors
    - Wiring guide for GC9A01 + MPU6050 + DS18B20 + MAX4466
    [starboy_star.scad]
2026-09-13 Complete rewrite: 500+ animations, 6480 eye designs, TFT_eSPI sprites
    - Seed-based eye generation: 20 iris colors x 6 patterns x 6 pupil
    shapes x 4 sclera tints x 4 highlight styles, rarity-gated
    - 50 base expressions blended smoothly via per-parameter interpolation,
    producing 500+ effective animation states
    - Full state machine: idle personality cycling, dizzy/angry from
    shake, chill/shiver/freeze from cold, startled/anxious/overwhelmed
    from sound, gravity-tracking tilt, doze/sleep/dreaming on idle
    - 20 rare special effects (rainbow, hearts, stars, glitch, matrix,
    hypno spiral, fire pupils, galaxy swirl, etc) on a random timer
    - Switched rendering to TFT_eSPI + off-screen sprite f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
    [User_Setup.h, starboy_firmware.ino]
2026-09-13 Finalize star shell geometry to match reference photos
    - Three-sphere hull per arm (center -> mid -> tip) instead of two,
    so arms stay chubby along their length and only round off near
    the tip, instead of tapering into a cone
    - Replaced flat disc-with-hole keyring boss with a real integrated
    bail: tapered bridge of material flows from the tip into a rounded
    torus loop, hole runs front-to-back so a bought keyring/carabiner
    hangs face-on exactly like the reference
    - Added a small faceted secondary-sensor accent on the opposite arm
    - Added a defined rim groove around the back medallion
    - Bumped body chubbiness (inner_radius, tip_round, valley_round)
    and medallion diameter to match p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
    [starboy_star.scad]
2026-09-13 Sleeken star shell to match reference photo — was too chubby
    - Longer, slimmer arms (outer_radius 28->31, inner_radius 11->8.5,
    tip_round 7->3.6) so arms read as tapered/sleek instead of chubby
    - Kept the 3-sphere-per-arm hull but tuned mid_r_ratio down (0.8->0.62)
    for a gentle continuous taper instead of a thick cylindrical arm
    - Shrunk back_medallion_dia (26->20) to fit within the now-slimmer
    core so its recess no longer slices into the tapered arm bases
    [starboy_star.scad]
2026-09-13 Shrink screen proportion, remove fake eye mockup for good
    - Enlarged body (outer_radius 31->34) and thinned the bezel ring
    (bezel_wall 2.2->1.6) so the fixed-size real display reads smaller
    against the star face instead of dominating it
    - screen_face_mockup() now shows only plain black glass — no green
    eye graphics. The eye is a physical display + firmware animation,
    not something to fake in the CAD preview (asked twice now)
    [starboy_star.scad]
2026-09-13 Rebuild star to reference proportions; add camera, vents, charge port
    Fixes two compounding geometry bugs that left the body nearly empty:
    - The cavity was shrinking tip/valley radii in POLAR terms, cutting the
    valley radius ~50% while barely touching the tips. Its arms hollowed
    out almost the whole body, leaving only a stub in the middle. Replaced
    with a true uniform offset inset, which is only safe now the centre
    is fat.
    - inner_radius was 7mm, so the central flat region was ~14mm across and
    could not host the 32.4mm display at all - the pocket was overhanging
    into empty space. Reference photos actually show a BIG central mass
    with SHORT crisp points (medallion ~55% of width)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
    [starboy_star.scad]
2026-09-13 Remove pure black from the eye palette - it rendered invisible
    Building a preview that runs the real seed + drawEye logic surfaced this:
    IRIS_PAL index 17 was 0x0000, pure black. That was harmless while a white
    sclera sat behind the iris, but now the eye is drawn flat onto a black
    field, so that variant showed nothing at all - just a floating pupil dot.
    Reachable on rare and legendary tiers.
    Swapped for 0xA000 deep crimson. Pure black must never go in this palette.
    [starboy_firmware.ino]
2026-09-13 Fix engraving breaking into cavity; add build asserts and buy guide
    Verifying the print before export caught two defects:
    1. The back engraving cut THROUGH into the electronics cavity. The
    medallion dish (1.6) plus its engraving (0.7) came to 2.3mm, against a
    2.2mm back wall - leaving a 0.6mm floor that the text then punched
    straight through. You would have seen into the electronics through the
    letters, with a dust and moisture path. Back wall is now a separate
    3.0mm, dish 1.2, engraving 0.5, leaving a solid 1.8mm floor.
    body_thickness raised 17 -> 18 to keep the component stack fitting.
    2. front_half and back_half were each cut with a (thickness/2 + 1) box,
    so both ha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
    [starboy_star.scad]
2026-09-13 Fix display pocket: 32.4mm is the GLASS, the PCB is 37.5mm
    Checking the display against Waveshare spec before buying caught a fit
    error that would have wasted the print and the part. Every listing quotes
    32.4mm for the GC9A01 1.28in module, but that is the display glass. The
    actual PCB is 37.5mm diameter. The pocket was 33.5mm - the module simply
    would not have gone in, 4mm short.
    - Pocket is now stepped: a 33.5mm opening at the face that the glass shows
    through, over a 38.6mm ledge that holds the real board, with a 2.55mm
    retaining lip. inner_radius 22 -> 23, outer_radius 35 -> 36 to keep the
    cavity clear of the wider ledge.
    - Asserts now test against the PCB diameter, not the glass.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
    [starboy_star.scad]
2026-09-13 Track the exported STLs; gitignore was swallowing them
    .gitignore had a blanket *.stl rule, so the print files never got
    committed - the repo looked complete but had no printable output in it.
    The stl/ folder is the deliverable, so it is now excluded from that rule.
    Exported at fine quality from the corrected geometry: stepped display
    pocket sized to the real 37.5mm PCB, 3.0mm back wall so the engraving
    cannot break into the cavity, halves splitting exactly on z=0, header
    notch on the 216 deg arm.
    Exported serially - an earlier run had two concurrent exports writing to
    the same folder, and those files were discarded rather than shipped.
    front 14308 tris / back 66126 tris / bezel 2661 tris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
    [starboy_back.stl, starboy_bezel.stl, starboy_front.stl]
2026-09-13 Fix three firmware bugs; new back rim text
    Mic: the MAX4466 output idles at mid-rail, about 2048 on a 12-bit ADC. The
    firmware compared the raw reading against 650, so a silent room read as
    loud and the eye sat in anxious forever. Now takes a short 32-sample burst
    and uses peak-to-peak, which is the actual sound level regardless of the
    DC offset. Threshold renamed LOUD_P2P since it means something different.
    Backlight: BL was wired straight to 3.3V, so the screen stayed fully lit
    even asleep with the eyes shut - a few hours of battery at best. BL moves
    to GPIO 7 on PWM; it eases down through doze and nearly off in sleep, and
    snaps back on wake. Handles both the ESP32 core 2.x and 3.x ledc A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
    [starboy_star.scad]
2026-09-13 Pre-print error pass: pocket fixes, print orientation, unverified sizes
    Display pocket:
    - The header-tab notch ran from z=3.0 to 9.5, straight out through the
    front face (top is 9.0), leaving a 10x14mm slot visible outside the
    bezel. The tab is on the PCB, so the notch now stops under the lip.
    - The PCB ledge ran 0.5mm into the retaining lip, thinning it from the
    intended 1.2mm to 0.7mm - the only thing holding the display in.
    Now stops exactly at the lip.
    - bezel_ring was drawn sunk 2.4mm into solid plastic. It is wider than
    the face opening, so it can only glue on the face; now sits there.
    Docs:
    - BUILD.md claimed no supports were needed. False: the keyring loop
    overhangs the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
    [starboy_back.stl, starboy_bezel.stl, starboy_star.scad]
2026-09-13 Front STL with the display pocket fixes
    Re-exported after the notch and lip fixes. Verified in the mesh itself:
    watertight (0 bad edges), display opening open through, retaining lip
    1.20mm, 1.20mm skin over the header-tab notch so no slot shows on the
    face, front wall 2.20mm. Front and back halves are both 77.85 x 64.08mm
    and exactly 9.00mm, meeting at z=0.
    [starboy_front.stl]
2026-09-13 Fix stale numbers left over from earlier revisions
    Comments and docs only - no geometry change, STLs unaffected.
    - usable central circle 39.6 -> 41.6mm (inner_radius went 22 -> 23)
    - README said 70mm point-to-point and ~$12 total; now the measured body
    size and the realistic $35-45, with the display marked as round PCB
    - WIRING.md said 17mm thick and a 4.8mm display in the pocket; now 18mm
    and 5.4mm inserted from inside against the lip
    [starboy_star.scad]
2026-09-13 Switch to Seeed XIAO ESP32C3; verified buying list in README
    The ESP32-C3 SuperMini has no battery charger - several sources confirm
    it, and the earlier docs claiming most boards include one were wrong. The
    XIAO ESP32C3 has a LiPo charger built in (380mA fast / 40mA trickle) and
    battery pads on its underside.
    Buying list moved into the README with names, prices and links, every
    one checked on the store page on 2026-09-13. The battery listing's own
    description confirms a protection circuit and 4x25x30mm size.
    Fit, re-checked against real numbers instead of guesses:
    - XIAO measures ~4.5mm over its USB-C socket, not the 3.2mm assumed for
    the SuperMini; the GY-521 is ~3.0mm with its chips, n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
    [starboy_star.scad]
2026-09-13 Switch buying list to AliExpress (~$30 vs $82 Amazon)
    Replace Amazon/Adafruit links with verified AliExpress alternatives:
    display $2.92, XIAO $5.36, MPU6050 $1.29, MAX4466 $0.87,
    DS18B20+adapter $1.09, 4.7kΩ kit $0.50, 402530 LiPo $3.75,
    carabiner 20-pack $1.09. Total drops from $82 to ~$30.
    Add separate 4.7kΩ resistor line (not bundled on AliExpress).
    Add pants carabiner clip listing.
    Also include re-exported STLs for final 20.5mm shell geometry.
    [starboy_back.stl, starboy_bezel.stl, starboy_front.stl]
2026-09-13 Add BOM.md with exact buy links for every part
    Standalone bill of materials at repo root for funding/expense
    approval: 11 line items, each with a direct product-page link
    (not a search page) and a checked price. Total ~$45.94 against
    a $120 budget.
    - Spray paint sourced from Amazon (Rust-Oleum Mirror Effect,
    $12.59) instead of AliExpress -- aerosols ship poorly/slowly
    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
2026-09-13 Fix all dead BOM links; switch to chrome spray; verify every URL
    - Replaced 5 dead AliExpress links (DS18B20, MAX4466, key rings,
    resistor kit, silicone wire) with working .aliexpress.us URLs,
    each browser-verified to load the correct product page
    - Updated prices to live values: display now $1.09, DS18B20 $0.77,
    MAX4466 $1.33, wire $3.33, resistors $1.09
    - Battery: switched to Amazon (ZhanMazwj 402530 2-pack, B09QHTSPZC)
    - Spray paint: changed from silver Mirror Effect to chrome Bright
    Coat (B000Z8DGXK) for actual chrome finish on the shell
    - All AliExpress links use aliexpress.us item format (tested)
    - Grand total updated: ~$41.37 (down from $45.94)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
2026-09-13 Add BOM.csv for Hack Club funding submission; rename hardware/ to CAD/
    Per the Hack Club Codex shipping guide (codex.hackclub.com/shipping/101):
    - Add BOM.csv with all 11 parts: item name, qty, unit price, total,
    supplier, direct buy link, and notes -- ready to submit for funding
    - Rename hardware/ to CAD/ to match the recommended folder structure
    - Update all references to CAD/starboy_star.scad in README, BOM, WIRING
    - BOM.md kept as the human-readable companion to BOM.csv
    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
    [BOM.csv, starboy_star.scad]
2026-09-14 switch parts to amazon, add step assembly, renders and wiring diagram
    aliexpress shipping (15-40 days) would miss the build date, so every part now
    ships from amazon. adds the .step assembly, readme renders and a wiring image
    that hack club shipping requires, plus a second-build list.
    [BOM.csv, starboy_assembly.step]
2026-09-14 bom covers both builds and filament
    [BOM.csv]
2026-09-14 drop black petg, print everything in white
    [BOM.csv]
2026-09-14 add starboy website with live interactive eyes
    static site in web/ for vercel: an eye that follows your cursor, buttons
    that play each sensor reaction and rare effect, all 100 colorways, and
    what's inside the star.
2026-09-14 redesign site in a light lilguy-style layout
    hero is a packed crowd of eyes that watch your cursor, the story section
    explains what our starboy does, and the view all bar opens a new eye looks
    page with all 400 looks, rarity tiers, shape filters and sorting.
2026-09-14 add devlog 1, own colorway names, license and unofficial labels
    renames all 100 colorways to our own names, adds an MIT license and a
    credits and legal section, labels the site and repo as an unofficial fan
    build, and adds the first devlog with 7 photo cards.
2026-09-14 add a hardware test sketch for checking parts before assembly
    tests the screen, backlight, i2c bus, mpu6050, ds18b20 and mic one by one,
    shows pass/fail on screen and serial, then live shake and sound bars.
    [hardware_test.ino]
2026-09-14 add serial tuning console, firmware now compiles
    type commands over usb to jump to any mood or rare effect, reroll eyes,
    fake cold or loud readings, and tune thresholds live with save to flash.
    both sketches build clean for the xiao esp32c3 on esp32 core 3.3.11.
2026-09-14 add sensor sandbox page and slow frame rate while asleep
    sandbox.html lets visitors drive temperature, noise and shake through a js
    copy of the firmware mood state machine. the firmware drops to 15fps when
    dozing and 8fps asleep to save battery.
    [starboy_firmware.ino]
2026-09-14 add a parity check between the firmware and web eye renderers
    tools/check_parity.js compares colorways, odds, pupil shapes, eye geometry
    and mood thresholds across the firmware, web/eyes.js, the preview page and
    the sensor sandbox, and flags colorway names that don't exist.
2026-09-14 shared mood module with tests, fix shake skipping the dizzy animation
    moves the sandbox state machine into web/mood.js and adds 17 fake-clock
    tests. writing them exposed a firmware bug: the shake interrupt returned
    every frame while shaking, so the spin animation never ran and mild dizzy
    could not escalate. the parity check now also compares mood timings.
    [starboy_firmware.ino]
2026-09-14 letter-by-letter text reveal and hover squish on the website
    headings rise in one letter at a time when scrolled into view and squish
    when hovered; paragraphs ripple in faster. links keep working, headings
    keep an aria-label, and reduced-motion visitors get plain text. reveal
    runs from an observer, scroll events and a timer so text can't get stuck
    hidden.
2026-09-14 fix tilt so a hanging keychain doesn't stay tilted and awake forever
    tilt was measured against lying flat, so a star hanging upright read 90
    degrees and stayed in S_TILT, which also refreshed the idle timer every
    frame, so it never dozed or dimmed. tilt is now measured against a
    slowly learned resting pose and no longer counts as attention. adds a
    tilt tracker to mood.js, a tilt slider to the sandbox, 5 tests and
    parity checks for the thresholds.
    [serial_console.ino, starboy_firmware.ino]
2026-09-14 make sensor smoothing frame-rate independent and keep listening while asleep
    the battery-saving frame rate (15fps dozing, 8fps asleep) slowed every
    per-frame smoothing: noise lingered 4x longer, shakes registered slower
    and dozing took twice as long. smoothing now scales with the real frame
    time, and the wait between frames keeps sampling the mic so a sleeping
    star doesn't miss a clap. parity check guards all of it.
    [starboy_firmware.ino]
2026-09-14 stop the cold mood flickering at 10c and add a temperature offset
    the ds18b20 jitters about 0.25c, so exiting chill at exactly the cold
    threshold flipped chill and idle on every reading. chill and shiver now
    need 1c of warmth to end. adds `set tempoffset` to the console to cancel
    heat from the board and battery, with a test and parity checks.
    [serial_console.ino, starboy_firmware.ino]
2026-09-14 one test command, no repeat rare effects, shared preview renderer, hw command
    tools/test_all.js runs parity, mood and seed tests and can build both
    sketches. rare effects never play twice in a row. eye_preview.html now
    loads web/eyes.js instead of keeping a third copy of the renderer. the
    console gets `hw`, which reports detected parts and the wire to check.
2026-09-14 update battery docs for the eemb 402535 in the bom
    the docs still described the 4.0mm 402530 the cad was first sized for.
    the 402535 is 4.3mm, so the stack is 11.8 of 12.0mm with 0.2mm slack; its
    footprint was already checked against the cavity. charge rate note fixed
    for 320mah.
2026-09-15 add a demo command that tours his moods for filming
    `demo` runs a 77s scripted tour: loud room, cold, shaken, four rare
    effects, falling asleep and waking. most steps only fake the sensors so
    the real mood logic reacts. tools/test_demo.js reads the step table from
    the firmware and replays it through mood.js; it caught the first draft
    letting him doze off mid-tour, so demo steps now count as attention.
2026-09-15 add a coded promo video for instagram
    promo/scene.js draws a 27.5s vertical video frame by frame with the real
    eye renderer and a chrome star drawn in code. render.js exports frames
    through headless edge, sfx.js synthesizes every sound effect and the beat
    from scratch, and make_video.js encodes the mp4 with ffmpeg.
2026-09-15 promo: cold open hook, comment vote, seamless loop
    opens straight on his panicked eyes with a hook line, then drops into the
    title. after the follow card, a vote asks which eyes he should get with
    four numbered looks, and look 1 grows back into the opening frame so the
    video loops. the beat starts on the drop and runs to the loop point.
2026-09-16 promo: --short builds a 21s cut from the same scene
2026-09-19 site: hop-in intro, dark chrome starboy, mint eyes, chrome product renders
    intro.js: starboy hops onto a dark stage, a spotlight finds him, and leap into the experience sends him into the camera; his screen opens like an iris onto the page. once per session, skips for reduced motion and deep links.
    star.js: dark chrome star shaded per pixel from a height field (bevel, dome, bezel ring, keyring) reflecting a studio; glass screen with a mint glow. shared hero look: mint eyes.
    tools/render_shell.js: offline renderer for the shell STLs in dark chrome (smooth normals, studio reflections, glass with glowing eyes, contact shadow, engraving occlusion).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
2026-09-19 site: bright chrome everywhere, intro on entry from any page, visitors can turn it off
    star.js + render_shell.js reflect a sky/horizon/ground world so the star reads as polished chrome, not black. bezels and nav star match.
    gate.js: entering the site on any page goes through the intro first and then continues there; moving between pages doesn't replay it. 'never show intro' in the intro and an on/off switch in every footer.
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2026-09-19 keyring hole through the star's point, black chrome renders
    CAD: bail_style = "hole" replaces the loop past the tip with a 5mm chamfered keyring hole 27.5mm out along the 0 deg arm (the arm the CAD already kept solid for the keyring load), sleeved through the hollow so the electronics bay stays closed. Two new asserts guard the arm walls and the display pocket. The old loop is still bail_style = "loop". STLs and the STEP assembly regenerated; body is now 64 x 61 x 20.5mm.
    renders: black chrome again (the intro keeps its bright chrome), with a steel split ring threaded through the new hole. intro star gets the hole too. docs updated.
    [starboy_assembly.step, starboy_back.stl, starboy_front.stl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]
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2026-09-26 bom: source from aliexpress, lcsc and seeed; parts total 134.74 -> 87.63
    [BOM.csv]
2026-09-26 bom: prototype board instead of a custom pcb; parts total 91.88
    [BOM.csv]
2026-09-26 bom: the prototype board gets cut into a circle
    [BOM.csv]
